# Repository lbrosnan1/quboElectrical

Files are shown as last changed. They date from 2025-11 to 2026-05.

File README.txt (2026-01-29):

Guys I have no idea what I'm doing here so if you have any suggestions lmk -Liam

Rules:

1) Only commit changes to the card you are meant to be working on
2) leave helpful commit messages
3) you don't need to follow the naming scheme because I'm pretty sure we can just see the date the latest change was
4) Put cool silkscreen on your boards

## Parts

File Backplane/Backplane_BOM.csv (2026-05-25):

Id | Designator | Footprint | Quantity | Designation | Supplier and ref
1 | J11,J33,J17,J5,J18,J13,J8,J15,J29,J31,J34,J14,J9,J35,J28,J7,J37,J10,J32,J30,J27,J36 | JST_PH_B2B-PH-K_1x02_P2.00mm_Vertical | 22 | Conn_01x02
2 | J24,J25,J26,J21,J23,J20,J22,J19 | PinHeader_1x02_P2.54mm_Vertical | 8 | Conn_01x02_Pin
3 | R2,R1 | R_0805_2012Metric | 2 | 120
4 | R4,R3 | R_0805_2012Metric | 2 | 4.7k
5 | J3,J2,J1,J4 | CONN_650470-5_TYC | 4 | ~
6 | U1 | SOIC-8_3.9x4.9mm_P1.27mm | 1 | ~
7 | J6 | SUPERSABRE_2CIRCUIT | 1 | 1720420202
8 | J12 | Molex_Mini-Fit_Jr_5566-24A_2x12_P4.20mm_Vertical | 1 | Conn_02x12_Odd_Even
9 | C2 | C_0805_2012Metric | 1 | 22uF
10 | C1,C3 | C_0805_2012Metric | 2 | 100nF

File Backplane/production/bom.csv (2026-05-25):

Designator | Footprint | Quantity | Value | LCSC Part #
C1, C3 | 0805 | 2 | 100nF
C2 | 0805 | 1 | 22uF
J1, J2, J3, J4 | CONN_650470-5_TYC | 4 | ~
J10, J11, J13, J14, J15, J17, J18, J27, J28, J29, J30, J31, J32, J33, J34, J35, J36, J37, J5, J7, J8, J9 | JST_PH_B2B-PH-K_1x02_P2.00mm_Vertical | 22 | Conn_01x02
J12 | Molex_Mini-Fit_Jr_5566-24A_2x12_P4.20mm_Vertical | 1 | Conn_02x12_Odd_Even
J19, J20, J21, J22, J23, J24, J25, J26 | PinHeader_1x02_P2.54mm_Vertical | 8 | Conn_01x02_Pin
J6 | SUPERSABRE_2CIRCUIT | 1 | 1720420202
R1, R2 | 0805 | 2 | 120
R3, R4 | 0805 | 2 | 4.7k
U1 | SOIC-8_3.9x4.9mm_P1.27mm | 1 | ~

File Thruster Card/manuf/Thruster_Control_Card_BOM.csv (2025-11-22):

Reference | Qty | Value | DNP | Exclude from BOM | Exclude from Board | Footprint | Datasheet
C1,C2 | 2 | 20pf |  |  |  | Capacitor_SMD:C_01005_0402Metric | ~
C4 | 1 | 4.7uF |  |  |  | Capacitor_SMD:C_0805_2012Metric_Pad1.18x1.45mm_HandSolder | ~
C5,C6,C7,T_C1,T_C3 | 5 | 100nF |  |  |  | Capacitor_SMD:C_0805_2012Metric_Pad1.18x1.45mm_HandSolder | ~
C8 | 1 | 1uF |  |  |  | Capacitor_SMD:C_0805_2012Metric_Pad1.18x1.45mm_HandSolder | ~
C9 | 1 | 22uF |  |  |  | Capacitor_SMD:C_0805_2012Metric_Pad1.18x1.45mm_HandSolder | ~
D1 | 1 | Green |  |  |  | LED_SMD:LED_1206_3216Metric_Pad1.42x1.75mm_HandSolder | ~
J1 | 1 | ~ |  |  |  | custom_components:6509475
J6 | 1 | Screw_Terminal_01x03 |  |  |  | custom_components:screw_junc_254_3by1 | ~
J7 | 1 | Screw_Terminal_01x02 |  |  |  | custom_components:screw_junc_254_2by1 | ~
R1 | 1 | 1k |  |  |  | Resistor_SMD:R_1206_3216Metric_Pad1.30x1.75mm_HandSolder | ~
R6 | 1 | 10k |  |  |  | Resistor_SMD:R_0805_2012Metric_Pad1.20x1.40mm_HandSolder | ~
SW1 | 1 | EG1218 |  |  |  | custom_components:slide_switch_EGER1218_Thruster | EG1218
U1,U3 | 2 | ~ |  |  |  | custom_components:ESC
U2,U4 | 2 | ~ |  |  |  | Thruster_Control_Card_Custom_Footprints:ESC
U5 | 1 | STM32G0B1RETx |  |  |  | Package_QFP:LQFP-64_10x10mm_P0.5mm | https://www.st.com/resource/en/datasheet/stm32g0b1re.pdf
U6 | 1 | ATA6561-GAQW-N |  |  |  | custom_components:SOIC8_4P9X3P9MC_MCH | ATA6561-GAQW-N
U7 | 1 | ~ |  |  |  | custom_components:YSX321SC_HSE_Oscillator

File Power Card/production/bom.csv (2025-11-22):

Designator | Footprint | Quantity | Value | LCSC Part #
C3, C6 | 0805 | 2 | 1u
J2 | 6509475 | 1 | ~
J3 | SolderWire-1.5sqmm_1x03_P7.8mm_D1.7mm_OD3.9mm | 1 | Conn_01x03_Pin
J4 | 1.25__FUSECLIPS | 1 | Conn_01x04_Pin
Q1 | TO-220-3_Vertical | 1 | FQPF27P06
R1, R2 | 0805 | 2 | 10kO
U1 | 240W_CONV | 1 | ~
U2 | CONV_UWE-24_3-Q12P-C | 1 | ~
U3 | TSR2 | 1 | TSR2-2450
U4 | TSR2 | 1 | TSR2-2433

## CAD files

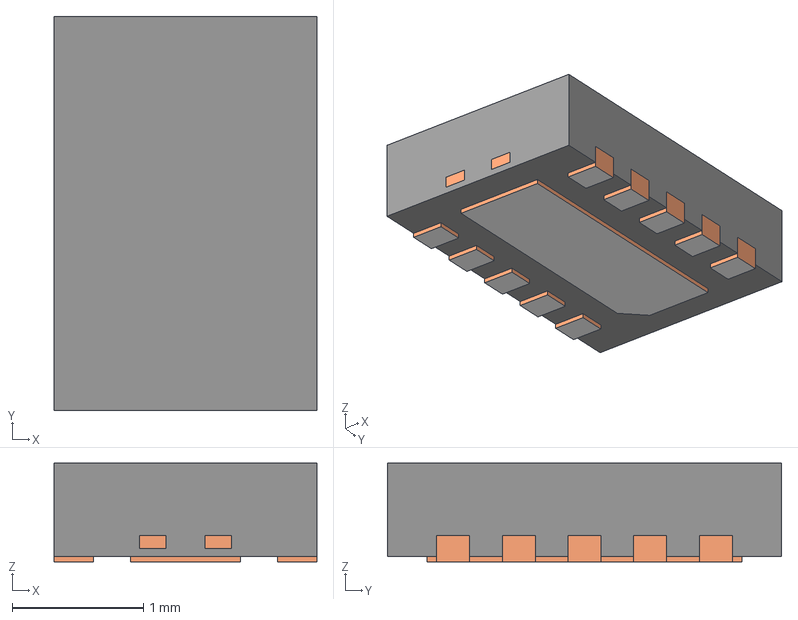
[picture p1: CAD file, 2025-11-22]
BMS Card/DQC0010A.stp
2.00 x 3.00 x 0.75 mm
MOLD-DQC0010A
FRAME-DQC0010A

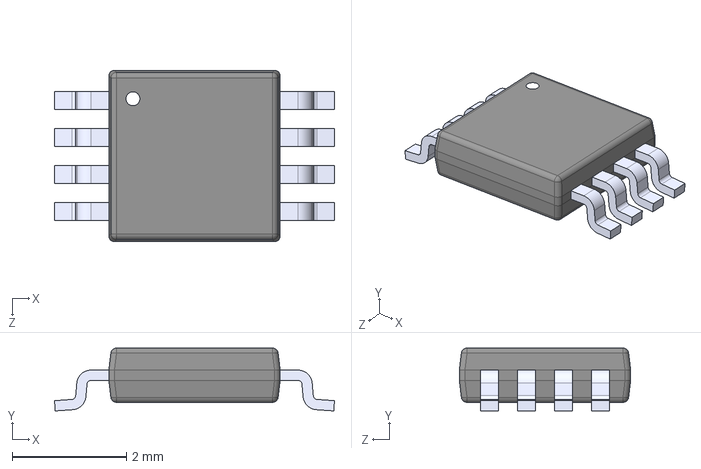
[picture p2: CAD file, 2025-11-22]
Pneumatics Card/3D models/TCA4307DGKR.STEP
4.90 x 1.10 x 3.00 mm

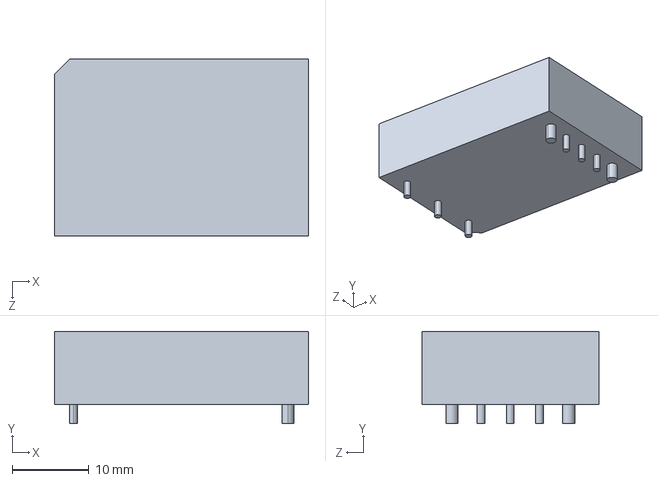
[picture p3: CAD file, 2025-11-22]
Power Card/3D_models/SRS3120N006N25W.STEP
33.1 x 12.0 x 23.1 mm

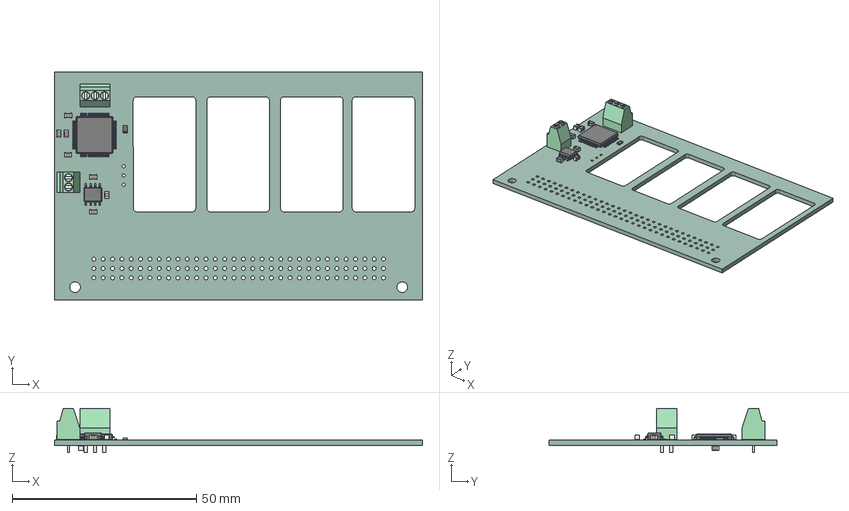
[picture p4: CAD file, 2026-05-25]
Thruster Card/Thruster_Control_Card.step
100.0 x 61.9 x 12.0 mm
TerminalBlock_Phoenix_MPT-0,5-2-2.54_1x02_P2.54mm_Horizontal
SO-8_3.9x4.9mm_P1.27mm
C_0805_2012Metric x 8
TerminalBlock_Phoenix_MPT-0,5-3-2.54_1x03_P2.54mm_Horizontal
R_0805_2012Metric
LQFP-64_10x10mm_P0.5mm
Thruster_Control_Card_PCB

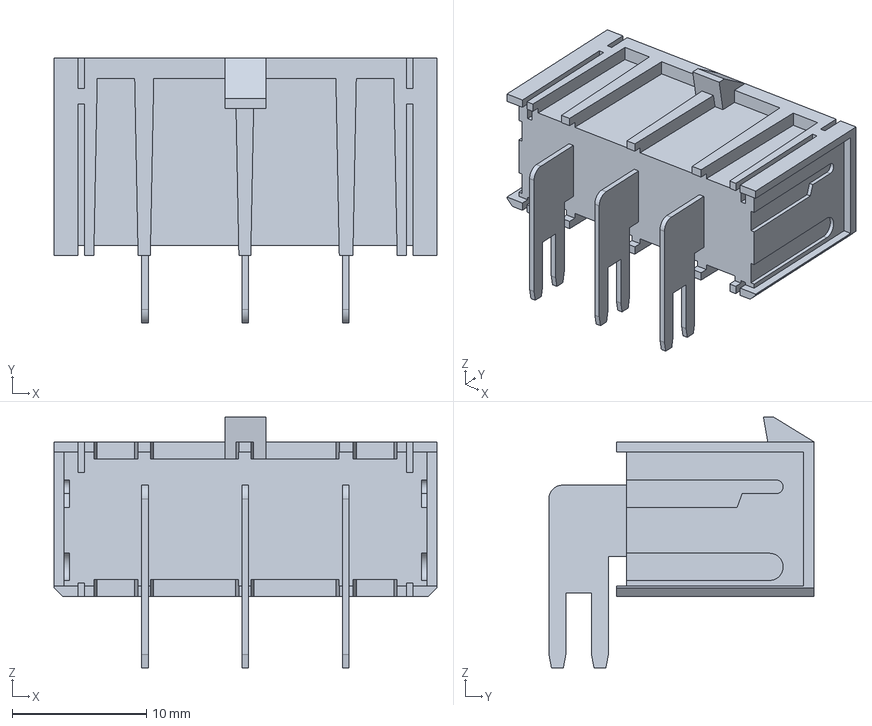
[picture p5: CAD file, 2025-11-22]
Power Card/3D_models/Saber_connector.stp
28.6 x 19.8 x 18.7 mm

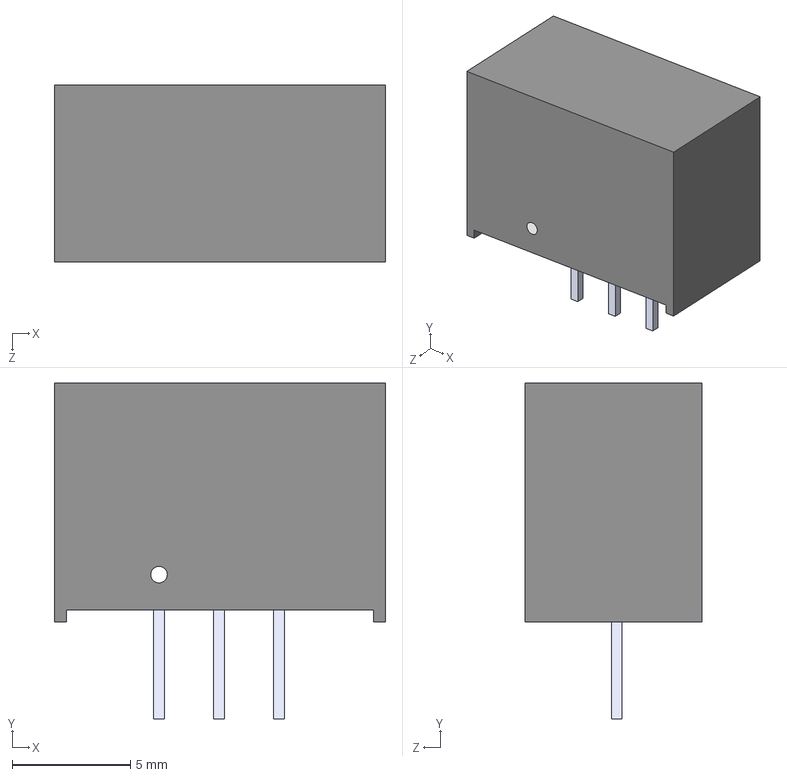
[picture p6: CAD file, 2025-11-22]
Power Card/3D_models/TSR_2-2450.step
14.0 x 14.2 x 7.50 mm

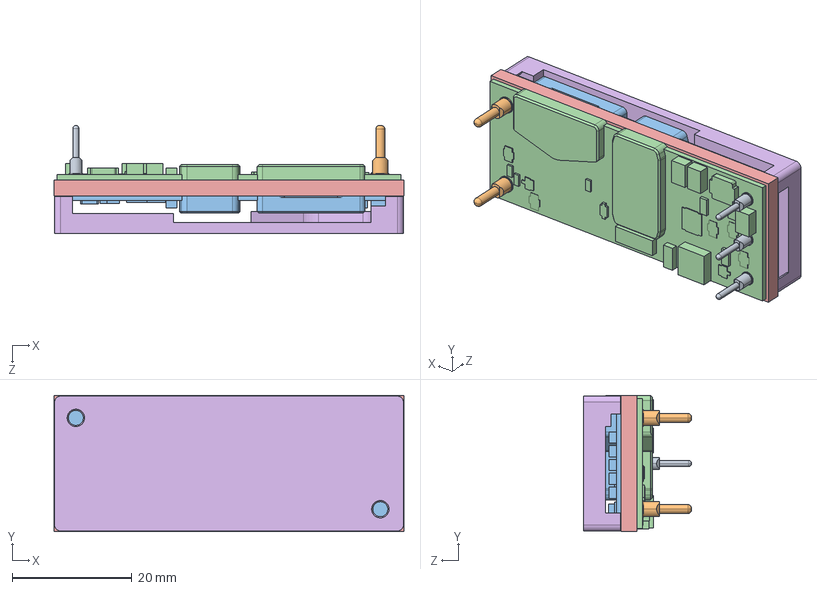
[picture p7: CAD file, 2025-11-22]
Power Card/3D_models/pkb2213dpihs.STEP
58.4 x 22.7 x 18.1 mm
pkb2213dpihs_01
pkb2213dpihs_02
pkb2213dpihs_03
pkb2213dpihs_04
pkb2213dpihs_05
pkb2213dpihs_06
pkb2213dpihs_07
pkb2213dpihs_08
pkb2213dpihs_09

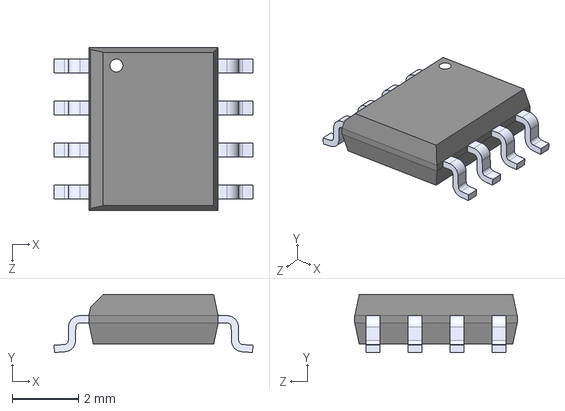
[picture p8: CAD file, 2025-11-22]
Power Card/3D_models/TMCS1101A4BQDR.step
6.00 x 1.75 x 4.90 mm

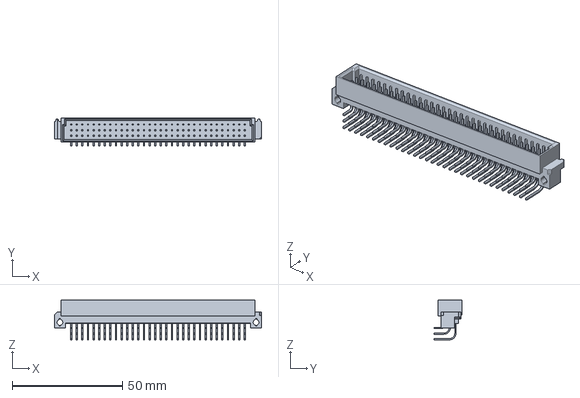
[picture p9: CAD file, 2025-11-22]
Power Card/3D_models/650947-5.stp
93.8 x 12.8 x 18.0 mm

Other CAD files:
Power Card/3D_models/SRS3120N006N25W.SLDPRT.STEP
Power Card/3D_models/SRS3120N006N25W.SLDPRT

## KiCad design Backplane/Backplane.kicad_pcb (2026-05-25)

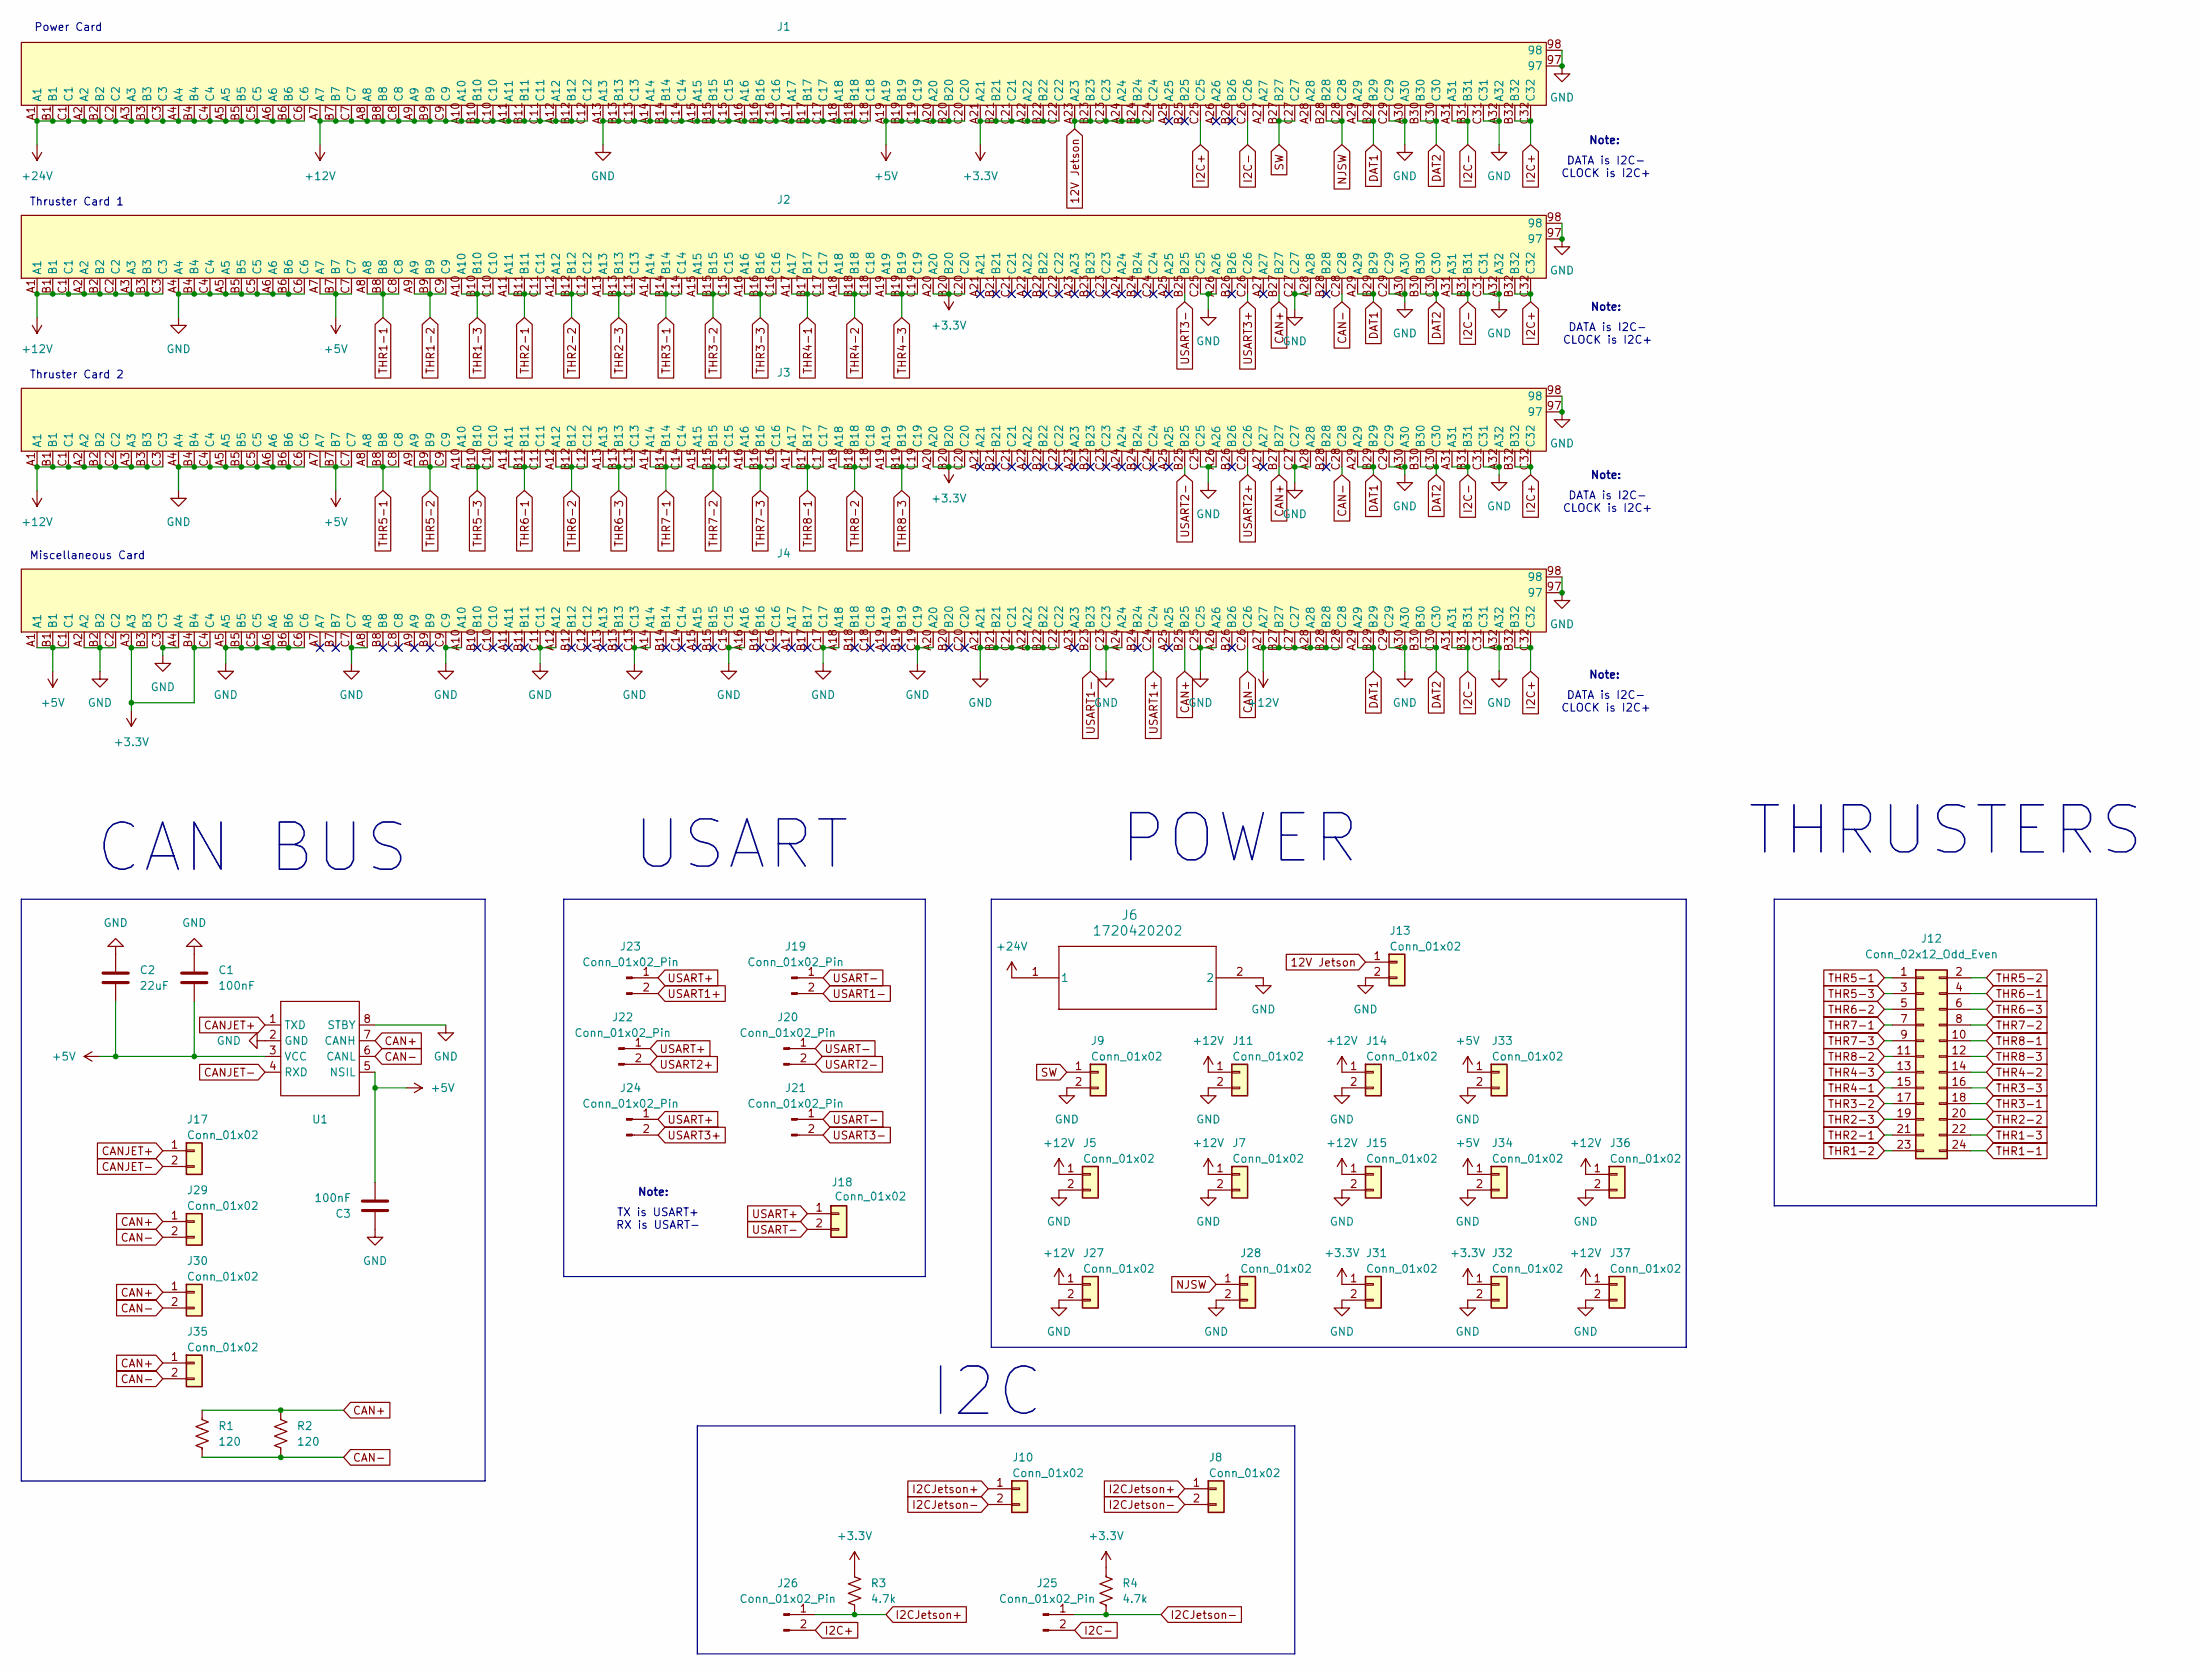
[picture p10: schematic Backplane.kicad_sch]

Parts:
C1, C3: 100nF; C_0805_2012Metric
C2: 22uF; C_0805_2012Metric
J1, J2, J3, J4: CONN_650470-5_TYC
J5, J7, J8, J9, J10, J11, J13, J14, J15, J17, J18, J27, J28, J29, J30, J31, J32, J33, J34, J35, J36, J37: Conn_01x02; JST_PH_B2B-PH-K_1x02_P2.00mm_Vertical
J6: 1720420202; SUPERSABRE_2CIRCUIT
J12: Conn_02x12_Odd_Even; Molex_Mini-Fit_Jr_5566-24A_2x12_P4.20mm_Vertical
J19, J20, J21, J22, J23, J24, J25, J26: Conn_01x02_Pin; PinHeader_1x02_P2.54mm_Vertical
R1, R2: 120; R_0805_2012Metric
R3, R4: 4.7k; R_0805_2012Metric
U1: SOIC-8_3.9x4.9mm_P1.27mm

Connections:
12V Jetson: J1.A23, J1.A24, J1.B23, J1.B24, J1.C23, J1.C24, J13.1
+3.3V: J1.A21, J1.A22, J1.B21, J1.B22, J1.C21, J1.C22, J2.A20, J2.B20, J2.C20, J3.A20, J3.B20, J3.C20, J4.A3, J4.B3, J4.B4, J4.C4, J31.1, J32.1, R3.1, R4.1
+5V: C1.2, C2.2, C3.2, J1.A19, J1.A20, J1.B19, J1.B20, J1.C19, J1.C20, J2.A7, J2.B7, J2.C7, J3.A7, J3.B7, J3.C7, J4.A1, J4.B1, J4.C1, J33.1, J34.1, U1.3 (VCC), U1.5 (NSIL)
+12V: J1.A7, J1.A8, J1.A9, J1.A10, J1.A11, J1.A12, J1.B7, J1.B8, J1.B9, J1.B10, J1.B11, J1.B12, J1.C7, J1.C8, J1.C9, J1.C10, J1.C11, J1.C12, J2.A1, J2.A2, J2.A3, J2.B1, J2.B2, J2.B3, J2.C1, J2.C2, J2.C3, J3.A1, J3.A2, J3.A3, J3.B1, J3.B2, J3.B3, J3.C1, J3.C2, J3.C3, J4.A27, J4.A28, J4.B27, J4.B28, J4.C27, J4.C28, J5.1, J7.1, J11.1, J14.1, J15.1, J27.1, J36.1, J37.1
+24V: J1.A1, J1.A2, J1.A3, J1.A4, J1.A5, J1.A6, J1.B1, J1.B2, J1.B3, J1.B4, J1.B5, J1.B6, J1.C1, J1.C2, J1.C3, J1.C4, J1.C5, J1.C6, J6.1
CAN+: J2.B27, J3.B27, J4.B25, J29.1, J30.1, J35.1, R1.1, R2.1, U1.7 (CANH)
CAN-: J2.C28, J3.C28, J4.C26, J29.2, J30.2, J35.2, R1.2, R2.2, U1.6 (CANL)
CANJET+: J17.1, U1.1 (TXD)
CANJET-: J17.2, U1.4 (RXD)
DAT1: J1.A29, J1.B29, J2.A29, J2.B29, J3.A29, J3.B29, J4.A29, J4.B29
DAT2: J1.B30, J1.C30, J2.B30, J2.C30, J3.B30, J3.C30, J4.B30, J4.C30
GND: C1.1, C2.1, C3.1, J1.97, J1.98, J1.A13, J1.A14, J1.A15, J1.A16, J1.A17, J1.A18, J1.A30, J1.A32, J1.B13, J1.B14, J1.B15, J1.B16, J1.B17, J1.B18, J1.C13, J1.C14, J1.C15, J1.C16, J1.C17, J1.C18, J1.C29, J1.C31, J2.97, J2.98, J2.A4, J2.A5, J2.A6, J2.A26, J2.A28, J2.A30, J2.A32, J2.B4, J2.B5, J2.B6, J2.C4, J2.C5, J2.C6, J2.C25, J2.C27, J2.C29, J2.C31, J3.97, J3.98, J3.A4, J3.A5, J3.A6, J3.A26, J3.A28, J3.A30, J3.A32, J3.B4, J3.B5, J3.B6, J3.C4, J3.C5, J3.C6, J3.C25, J3.C27, J3.C29, J3.C31, J4.97, J4.98, J4.A2, J4.A4, J4.A5, J4.A6, J4.A8, J4.A10, J4.A12, J4.A14, J4.A16, J4.A18, J4.A20, J4.A21, J4.A22, J4.A24, J4.A26, J4.A30, J4.A32, J4.B2, J4.B5, J4.B6, J4.B21, J4.B22, J4.C2, J4.C3, J4.C5, J4.C6, J4.C7, J4.C9, J4.C11, J4.C13, J4.C15, J4.C17, J4.C19, J4.C21, J4.C22, J4.C23, J4.C25, J4.C29, J4.C31, J5.2, J6.2, J7.2, J9.2, J11.2, J13.2, J14.2, J15.2, J27.2, J28.2, J31.2, J32.2, J33.2, J34.2, J36.2, J37.2, U1.2 (GND), U1.8 (STBY)
I2C+: J1.B32, J1.C25, J1.C32, J2.B32, J2.C32, J3.B32, J3.C32, J4.B32, J4.C32, J26.2
I2C-: J1.A31, J1.B31, J1.C26, J2.A31, J2.B31, J3.A31, J3.B31, J4.A31, J4.B31, J25.2
I2CJetson+: J8.1, J10.1, J26.1, R3.2
I2CJetson-: J8.2, J10.2, J25.1, R4.2
NJSW: J1.B28, J1.C28, J28.1
SW: J1.B27, J1.C27, J9.1
THR1-1: J2.A8, J2.B8, J2.C8, J12.24
THR1-2: J2.A9, J2.B9, J2.C9, J12.23
THR1-3: J2.A10, J2.B10, J2.C10, J12.22
THR2-1: J2.A11, J2.B11, J2.C11, J12.21
THR2-2: J2.A12, J2.B12, J2.C12, J12.20
THR2-3: J2.A13, J2.B13, J2.C13, J12.19
THR3-1: J2.A14, J2.B14, J2.C14, J12.18
THR3-2: J2.A15, J2.B15, J2.C15, J12.17
THR3-3: J2.A16, J2.B16, J2.C16, J12.16
THR4-1: J2.A17, J2.B17, J2.C17, J12.15
THR4-2: J2.A18, J2.B18, J2.C18, J12.14
THR4-3: J2.A19, J2.B19, J2.C19, J12.13
THR5-1: J3.A8, J3.B8, J3.C8, J12.1
THR5-2: J3.A9, J3.B9, J3.C9, J12.2
THR5-3: J3.A10, J3.B10, J3.C10, J12.3
THR6-1: J3.A11, J3.B11, J3.C11, J12.4
THR6-2: J3.A12, J3.B12, J3.C12, J12.5
THR6-3: J3.A13, J3.B13, J3.C13, J12.6
THR7-1: J3.A14, J3.B14, J3.C14, J12.7
THR7-2: J3.A15, J3.B15, J3.C15, J12.8
THR7-3: J3.A16, J3.B16, J3.C16, J12.9
THR8-1: J3.A17, J3.B17, J3.C17, J12.10
THR8-2: J3.A18, J3.B18, J3.C18, J12.11
THR8-3: J3.A19, J3.B19, J3.C19, J12.12
USART1+: J4.C24, J23.2
USART1-: J4.B23, J19.2
USART2+: J3.C26, J22.2
USART2-: J3.B25, J20.2
USART3+: J2.C26, J24.2
USART3-: J2.B25, J21.2
USART+: J18.1, J22.1, J23.1, J24.1
USART-: J18.2, J19.1, J20.1, J21.1

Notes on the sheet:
I2C
Note:
POWER
Thruster Card 1
DATA is I2C- CLOCK is I2C+
Miscellaneous Card
THRUSTERS
Power Card
USART
Thruster Card 2
CAN BUS
TX is USART+ RX is USART-

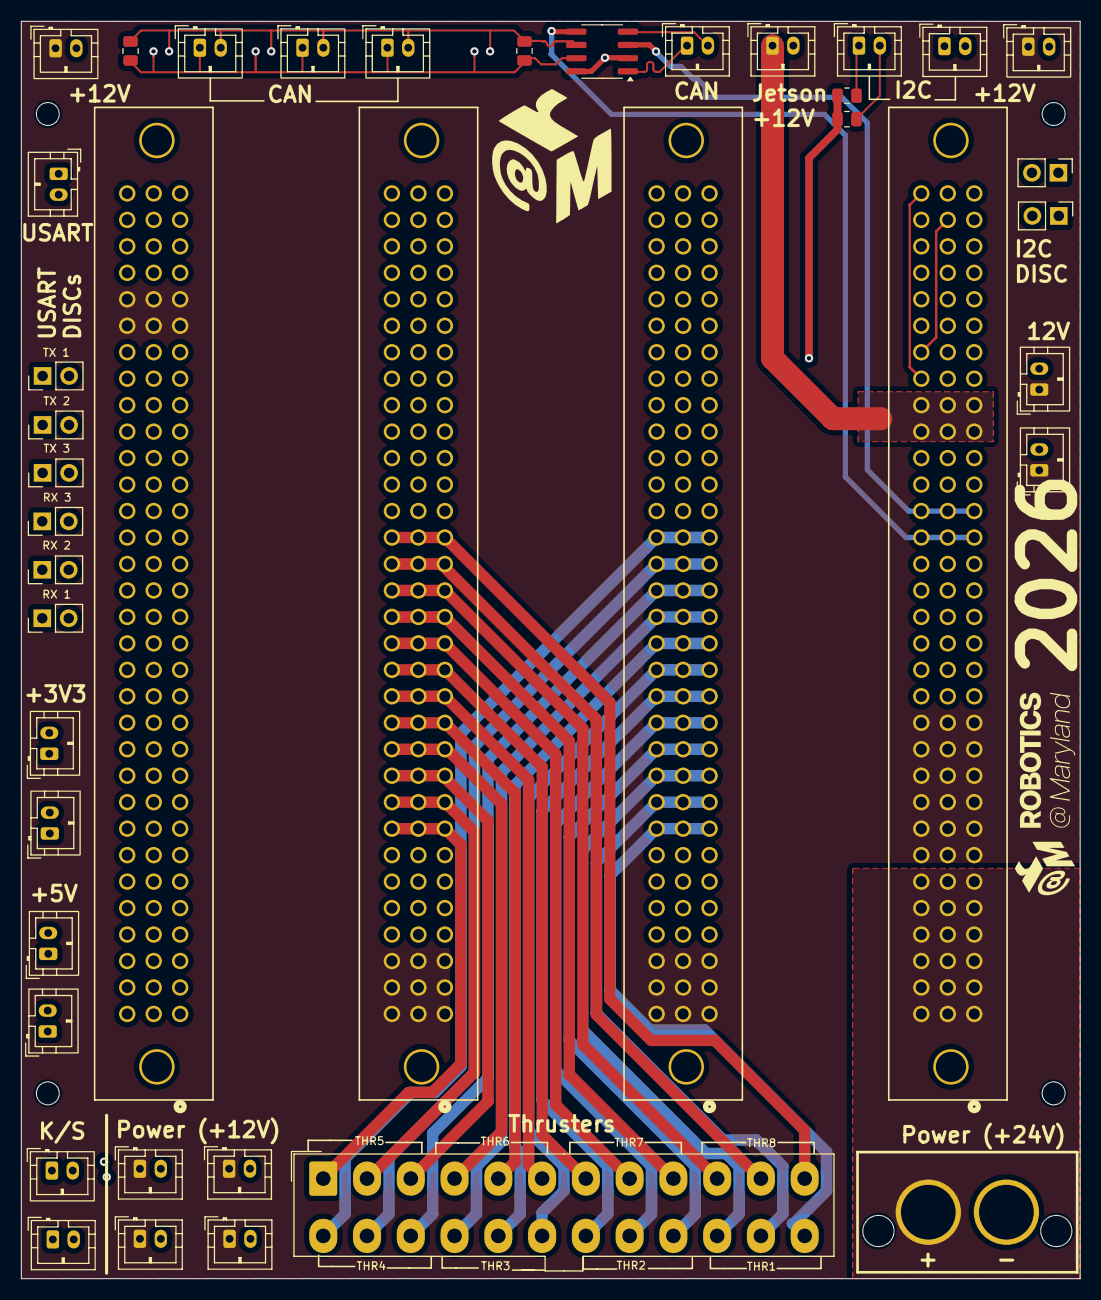
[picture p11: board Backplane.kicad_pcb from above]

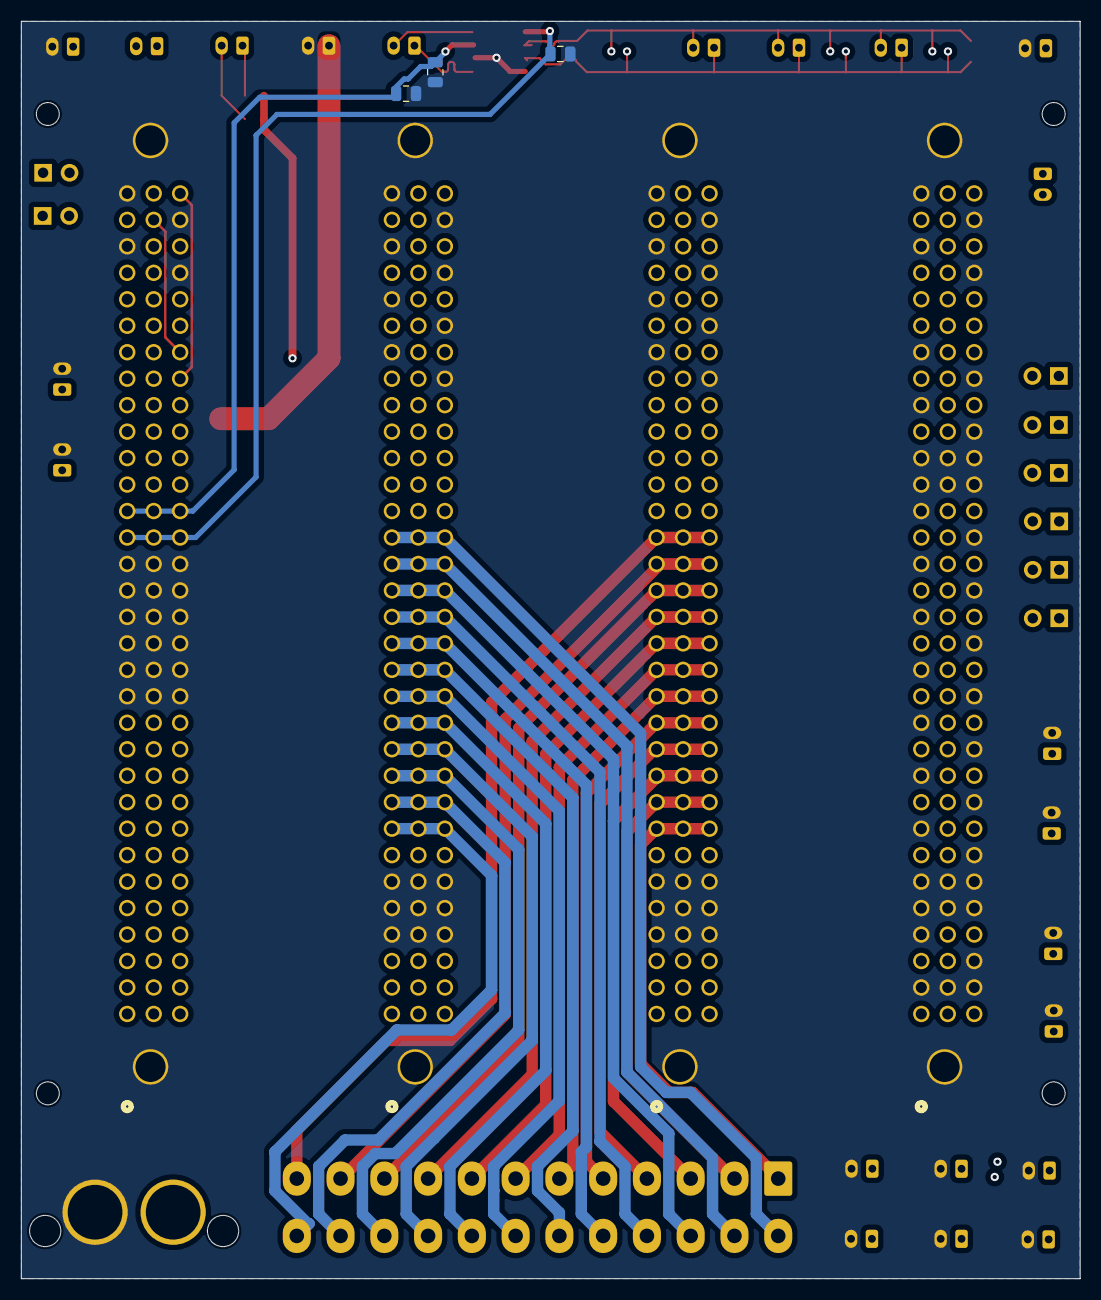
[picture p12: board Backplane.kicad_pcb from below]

Board: 4 copper layers, 101.6 x 120.6 mm, 44 parts (3 on the bottom side), 50 nets.

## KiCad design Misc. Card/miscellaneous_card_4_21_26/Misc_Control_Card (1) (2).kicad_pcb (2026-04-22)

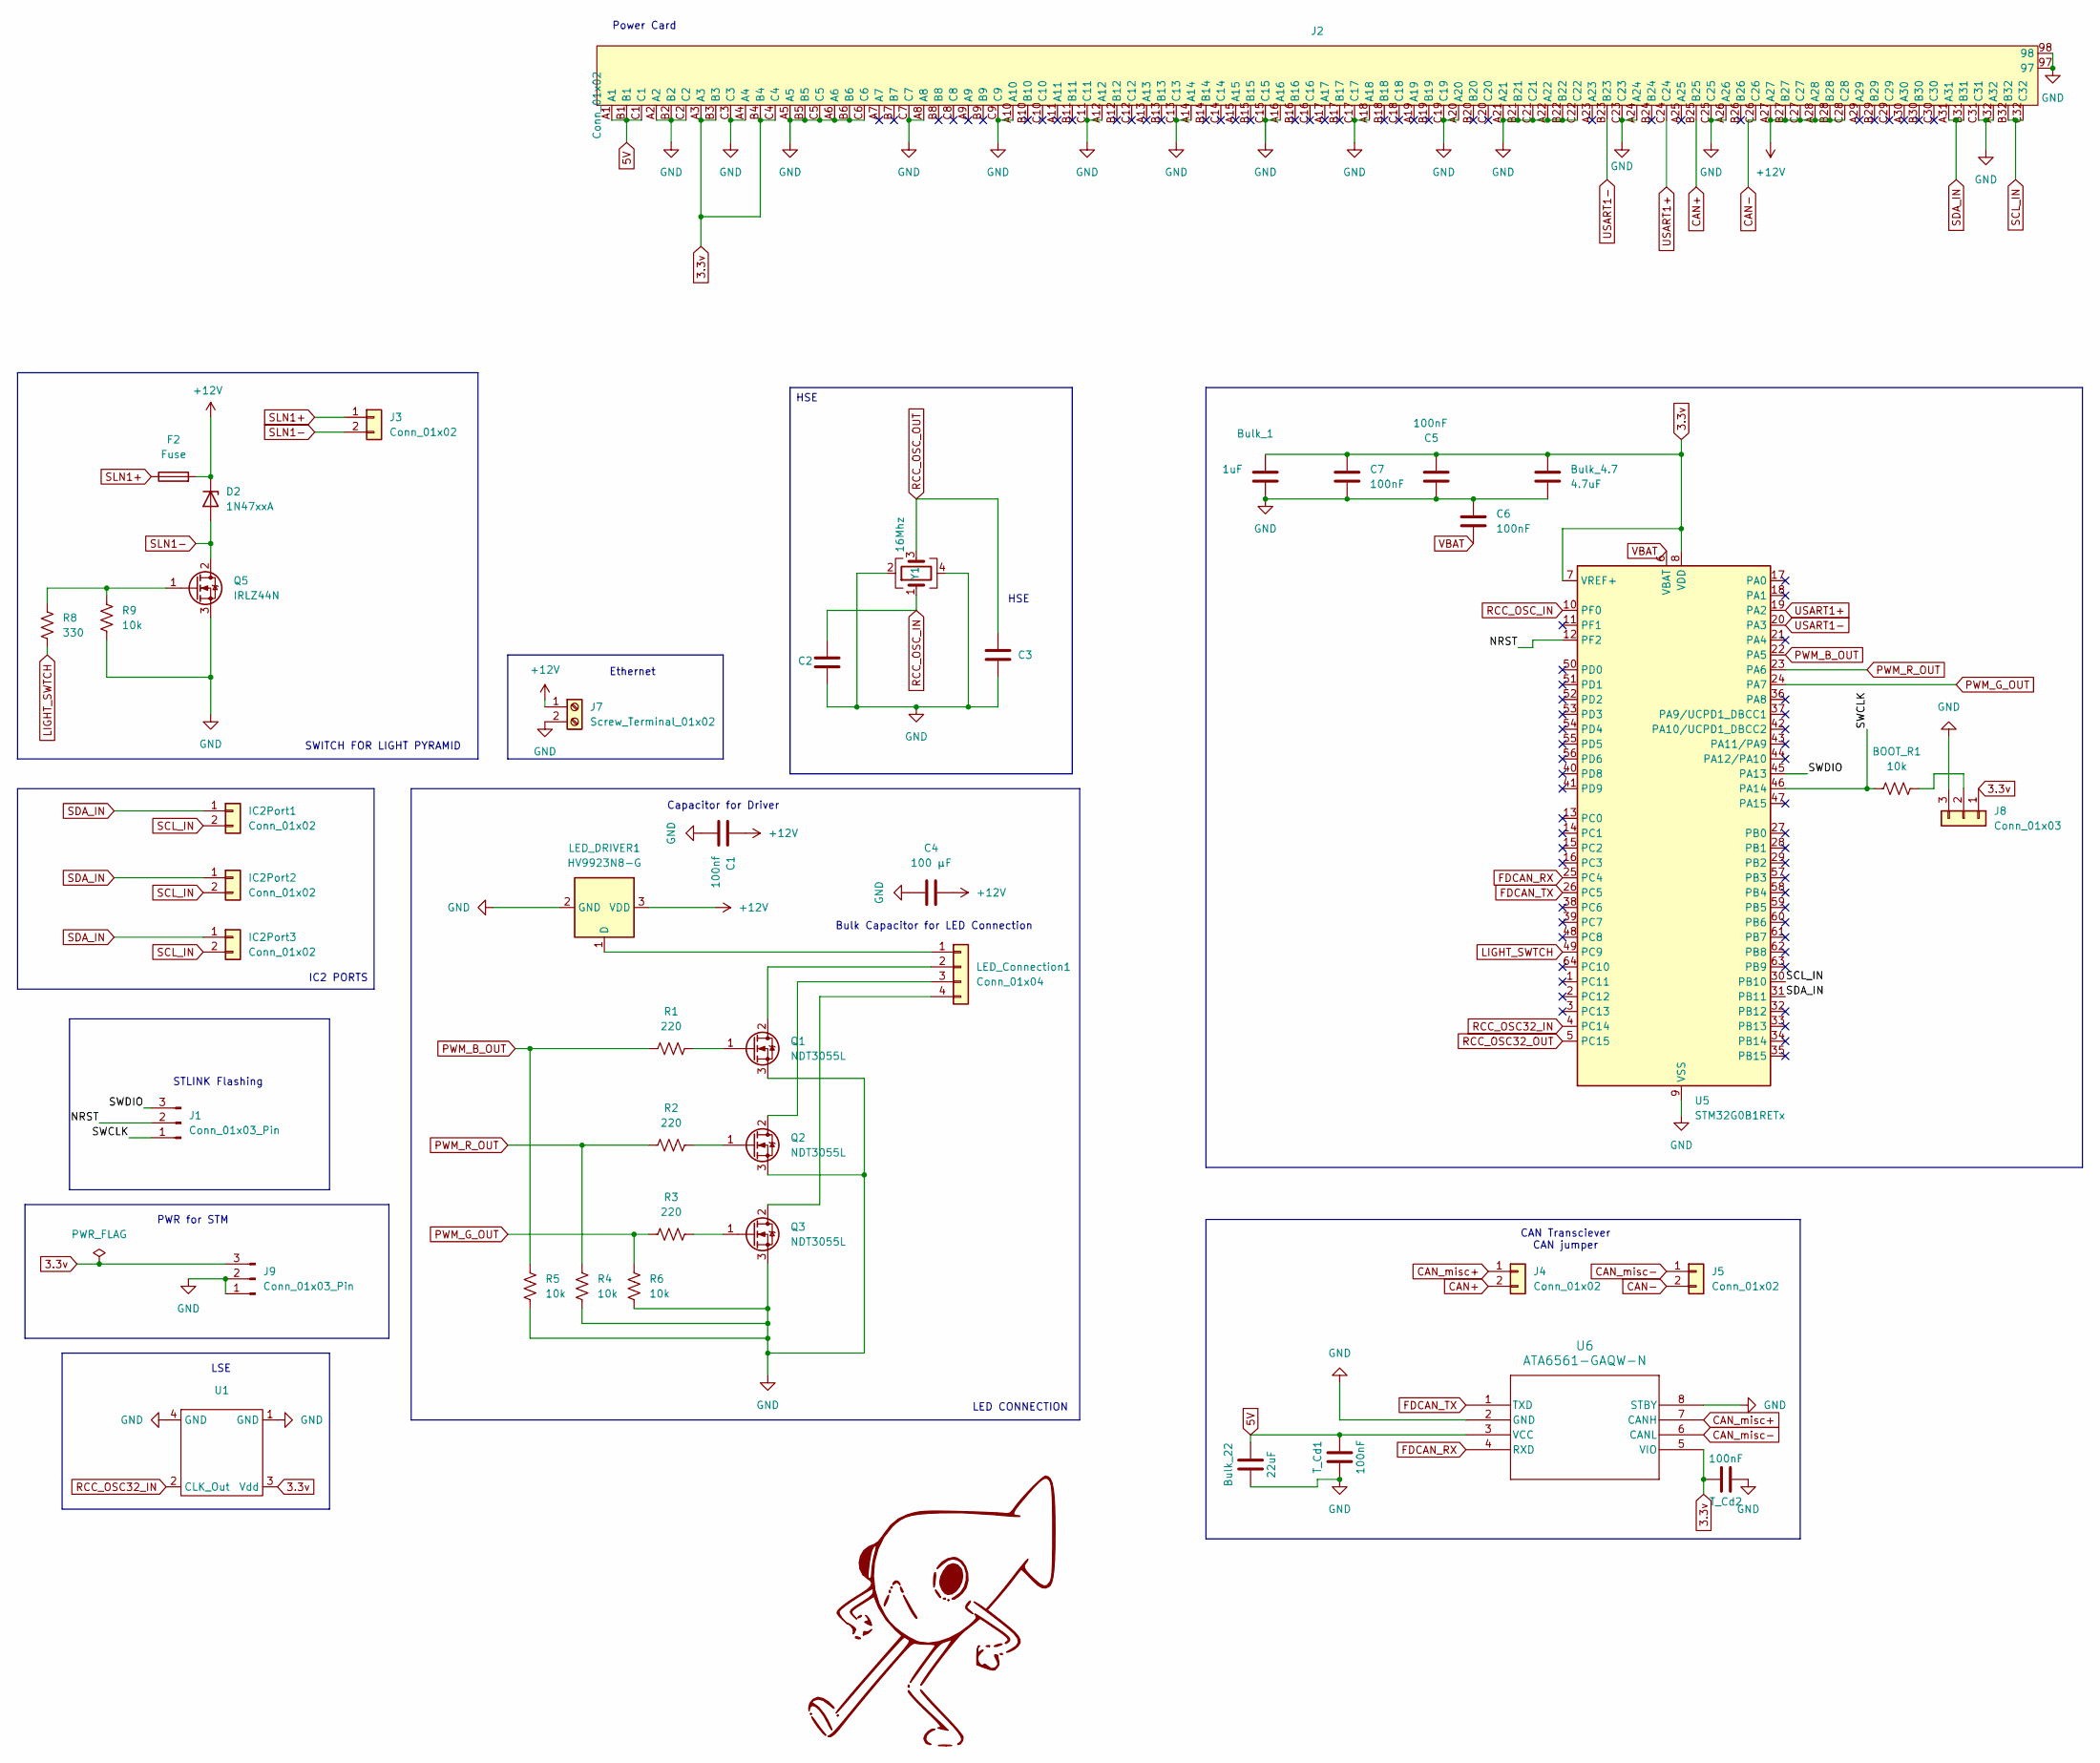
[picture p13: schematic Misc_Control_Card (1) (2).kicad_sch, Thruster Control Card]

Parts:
BOOT_R1: 10k; R_0805_2012Metric_Pad1.20x1.40mm_HandSolder
Bulk_1: 1uF; C_0805_2012Metric_Pad1.18x1.45mm_HandSolder
Bulk_4.7: 4.7uF; C_0805_2012Metric_Pad1.18x1.45mm_HandSolder
Bulk_22: 22uF; C_0805_2012Metric_Pad1.18x1.45mm_HandSolder
C1: 100nf; C_0805_2012Metric_Pad1.18x1.45mm_HandSolder
C2, C3: 10pF; C_0805_2012Metric_Pad1.18x1.45mm_HandSolder
C4: 100 µF; C_0805_2012Metric_Pad1.18x1.45mm_HandSolder
C5, C6, C7: 100nF; C_0805_2012Metric_Pad1.18x1.45mm_HandSolder
D2: 1N47xxA; D_DO-41_SOD81_P10.16mm_Horizontal
F2: Fuse; Fuseholder_Littelfuse_Nano2_154x
IC2Port1, IC2Port2, IC2Port3: Conn_01x02; JST_PH_B2B-PH-K_1x02_P2.00mm_Vertical
J1, J9: Conn_01x03_Pin; PinHeader_1x03_P2.54mm_Vertical
J2: Conn_01x02; 6509475
J3: Conn_01x02; JST_PH_B2B-PH-K_1x02_P2.00mm_Vertical
J4, J5: Conn_01x02; PinHeader_1x02_P2.54mm_Vertical
J7: Screw_Terminal_01x02; screw_junc_254_2by1
J8: Conn_01x03; slide_switch_EGER1218_Thruster
LED_Connection1: Conn_01x04; JST_EH_B4B-EH-A_1x04_P2.50mm_Vertical
LED_DRIVER1: HV9923N8-G; SOT-89-3
Q1, Q2, Q3: NDT3055L; SOT-223-3_TabPin2
Q5: IRLZ44N; TO-220-3_Vertical
R1, R2, R3: 220; R_0805_2012Metric_Pad1.20x1.40mm_HandSolder
R4, R5, R6, R9: 10k; R_0805_2012Metric_Pad1.20x1.40mm_HandSolder
R8: 330; R_0805_2012Metric_Pad1.20x1.40mm_HandSolder
T_Cd1, T_Cd2: 100nF; C_0805_2012Metric_Pad1.18x1.45mm_HandSolder
U1: SiT1552
U5: STM32G0B1RETx; LQFP-64_10x10mm_P0.5mm
U6: ATA6561-GAQW-N; SOIC8_4P9X3P9MC_MCH
Y1: 16Mhz; Crystal_SMD_3225-4Pin_3.2x2.5mm_HandSoldering

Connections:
3.3v: Bulk_1.2, Bulk_4.7.1, C5.1, C7.1, J1.A3, J1.B3, J1.B4, J1.C4, J2.A3, J2.B3, J2.B4, J2.C4, J8.1, J9.3, T_Cd2.1, U1.3 (Vdd), U5.7 (VREF+), U5.8 (VDD), U6.5 (VIO); also elsewhere on the board
5V: Bulk_22.1, J2.A1, J2.B1, J2.C1, T_Cd1.1, U6.3 (VCC)
+12V: C1.1, C4.1, D2.1 (K), F2.2, J1.A27, J1.A28, J1.B27, J1.B28, J1.C27, J1.C28, J2.A27, J2.A28, J2.B27, J2.B28, J2.C27, J2.C28, J7.1, LED_DRIVER1.3 (VDD); also elsewhere on the board
/NRST: J1.2, U5.12 (PF2)
/SWCLK: BOOT_R1.1, J1.1, U5.46 (PA14)
/SWDIO: J1.3, U5.45 (PA13)
CAN+: J2.B25, J4.2
CAN-: J2.C26, J5.2
CAN_misc+: J4.1, U6.7 (CANH)
CAN_misc-: J5.1, U6.6 (CANL)
FDCAN_RX: U5.25 (PC4), U6.4 (RXD)
FDCAN_TX: U5.26 (PC5), U6.1 (TXD)
GND: Bulk_1.1, Bulk_4.7.2, Bulk_22.2, C1.2, C2.2, C3.2, C4.2, C5.2, C6.1, C7.2, J1.97, J1.98, J1.A2, J1.A4, J1.A5, J1.A6, J1.A8, J1.A10, J1.A12, J1.A14, J1.A16, J1.A18, J1.A20, J1.A21, J1.A22, J1.A24, J1.A26, J1.A32, J1.B2, J1.B5, J1.B6, J1.B21, J1.B22, J1.C2, J1.C3, J1.C5, J1.C6, J1.C7, J1.C9, J1.C11, J1.C13, J1.C15, J1.C17, J1.C19, J1.C21, J1.C22, J1.C23, J1.C25, J1.C31, J2.97, J2.98, J2.A2, J2.A4, J2.A5, J2.A6, J2.A8, J2.A10, J2.A12, J2.A14, J2.A16, J2.A18, J2.A20, J2.A21, J2.A22, J2.A24, J2.A26, J2.A32, J2.B2, J2.B5, J2.B6, J2.B21, J2.B22, J2.C2, J2.C3, J2.C5, J2.C6, J2.C7, J2.C9, J2.C11, J2.C13, J2.C15, J2.C17, J2.C19, J2.C21, J2.C22, J2.C23, J2.C25, J2.C31, J7.2, J8.3, J9.1, J9.2, LED_DRIVER1.2 (GND), Q1.3 (S), Q2.3 (S), Q3.3 (S), Q5.3 (S), R4.1, R5.1, R6.1, R9.2, T_Cd1.2, T_Cd2.2, U1.1 (GND), U1.4 (GND), U5.9 (VSS), U6.2 (GND), U6.8 (STBY), Y1.2, Y1.4; also elsewhere on the board
LIGHT_SWTCH: R8.1, U5.49 (PC9)
unnamed: BOOT_R1.2, J8.2
unnamed 15: LED_Connection1.1, LED_DRIVER1.1 (D); also elsewhere on the board
unnamed 16: LED_Connection1.2, Q1.2 (D); also elsewhere on the board
unnamed 17: LED_Connection1.3, Q2.2 (D); also elsewhere on the board
unnamed 18: LED_Connection1.4, Q3.2 (D); also elsewhere on the board
unnamed: Q1.1 (G), R1.2
unnamed: Q2.1 (G), R2.2
unnamed: Q3.1 (G), R3.2
unnamed 22: Q5.1 (G), R8.2, R9.1; also elsewhere on the board
PWM_B_OUT: R1.1, R5.2, U5.22 (PA5)
PWM_G_OUT: R3.1, R6.2, U5.24 (PA7)
PWM_R_OUT: R2.1, R4.2, U5.23 (PA6)
RCC_OSC32_IN: U1.2 (CLK_Out), U5.4 (PC14)
RCC_OSC32_OUT: U5.5 (PC15)
RCC_OSC_IN: C2.1, U5.10 (PF0), Y1.1
RCC_OSC_OUT: C3.1, Y1.3
SCL_IN: IC2Port1.2, IC2Port2.2, IC2Port3.2, J2.B32, J2.C32, U5.30 (PB10)
SDA_IN: IC2Port1.1, IC2Port2.1, IC2Port3.1, J2.A31, J2.B31, U5.31 (PB11)
SLN1+: F2.1, J3.1
SLN1-: D2.2 (A), J3.2, Q5.2 (D); also elsewhere on the board
USART1+: J2.C24, U5.19 (PA2)
USART1-: J2.B23, U5.20 (PA3)
VBAT: C6.2, U5.6 (VBAT)

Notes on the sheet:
Bulk Capacitor for LED Connection
Power Card
LSE
IC2 PORTS
Capacitor for Driver
STLINK Flashing
PWR for STM
CAN Transciever CAN jumper
SWITCH FOR LIGHT PYRAMID
HSE
LED CONNECTION
Ethernet
HSE

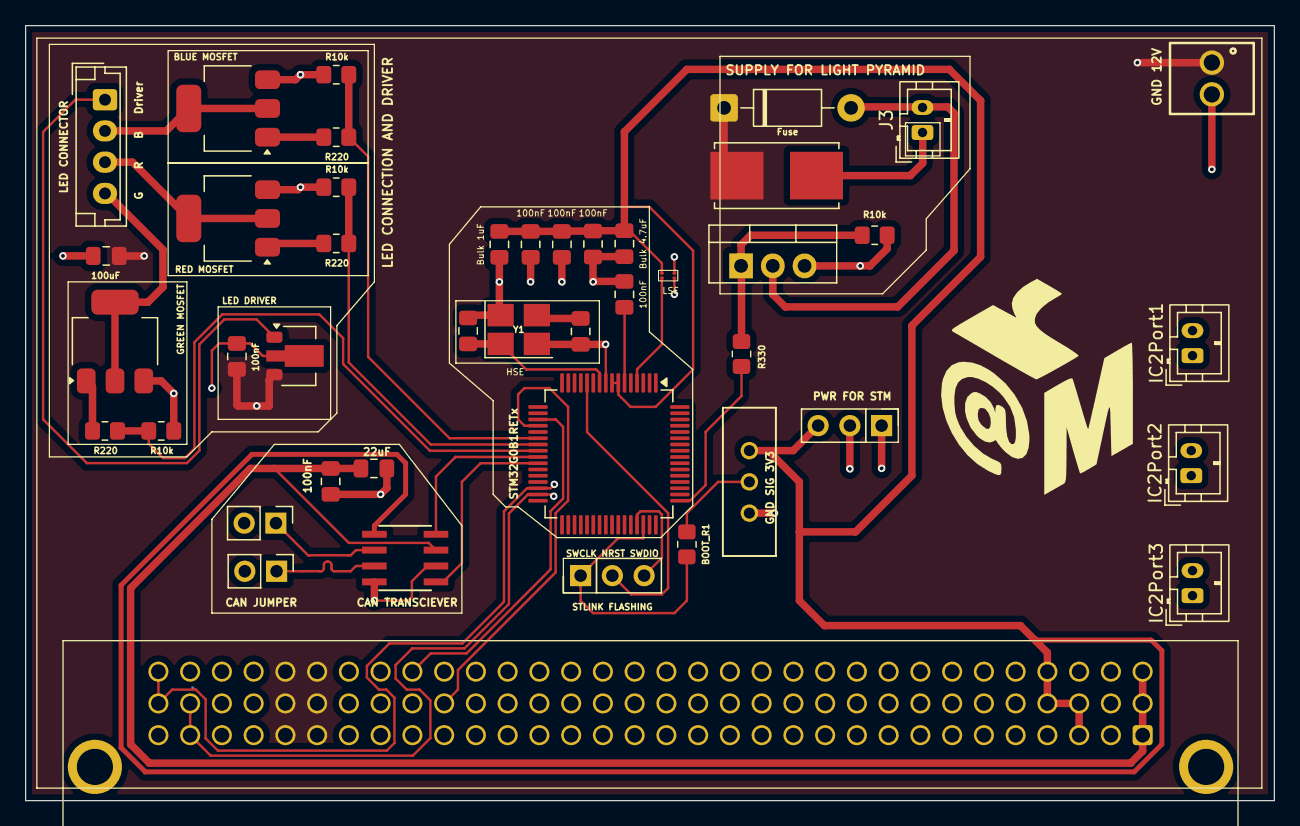
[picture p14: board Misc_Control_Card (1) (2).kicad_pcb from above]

Board: 4 copper layers, 99.9 x 62.0 mm, 44 parts (0 on the bottom side), 36 nets.

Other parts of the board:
Bulk 4.7uF: 4.7uF; C_0805_2012Metric_Pad1.18x1.45mm_HandSolder
Fuse: 1N47xxA; D_DO-41_SOD81_P10.16mm_Horizontal
LED Connection: Conn_01x04; JST_EH_B4B-EH-A_1x04_P2.50mm_Vertical
R10k: 10k; R_0805_2012Metric_Pad1.20x1.40mm_HandSolder

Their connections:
3.3v: Bulk 4.7uF.1; also elsewhere on the board
+12V: Fuse.1 (K); also elsewhere on the board
GND: Bulk 4.7uF.2, R10k.2; also elsewhere on the board
unnamed 15: LED Connection.1; also elsewhere on the board
unnamed 16: LED Connection.2; also elsewhere on the board
unnamed 17: LED Connection.3; also elsewhere on the board
unnamed 18: LED Connection.4; also elsewhere on the board
unnamed 22: R10k.1; also elsewhere on the board
SLN1-: Fuse.2 (A); also elsewhere on the board

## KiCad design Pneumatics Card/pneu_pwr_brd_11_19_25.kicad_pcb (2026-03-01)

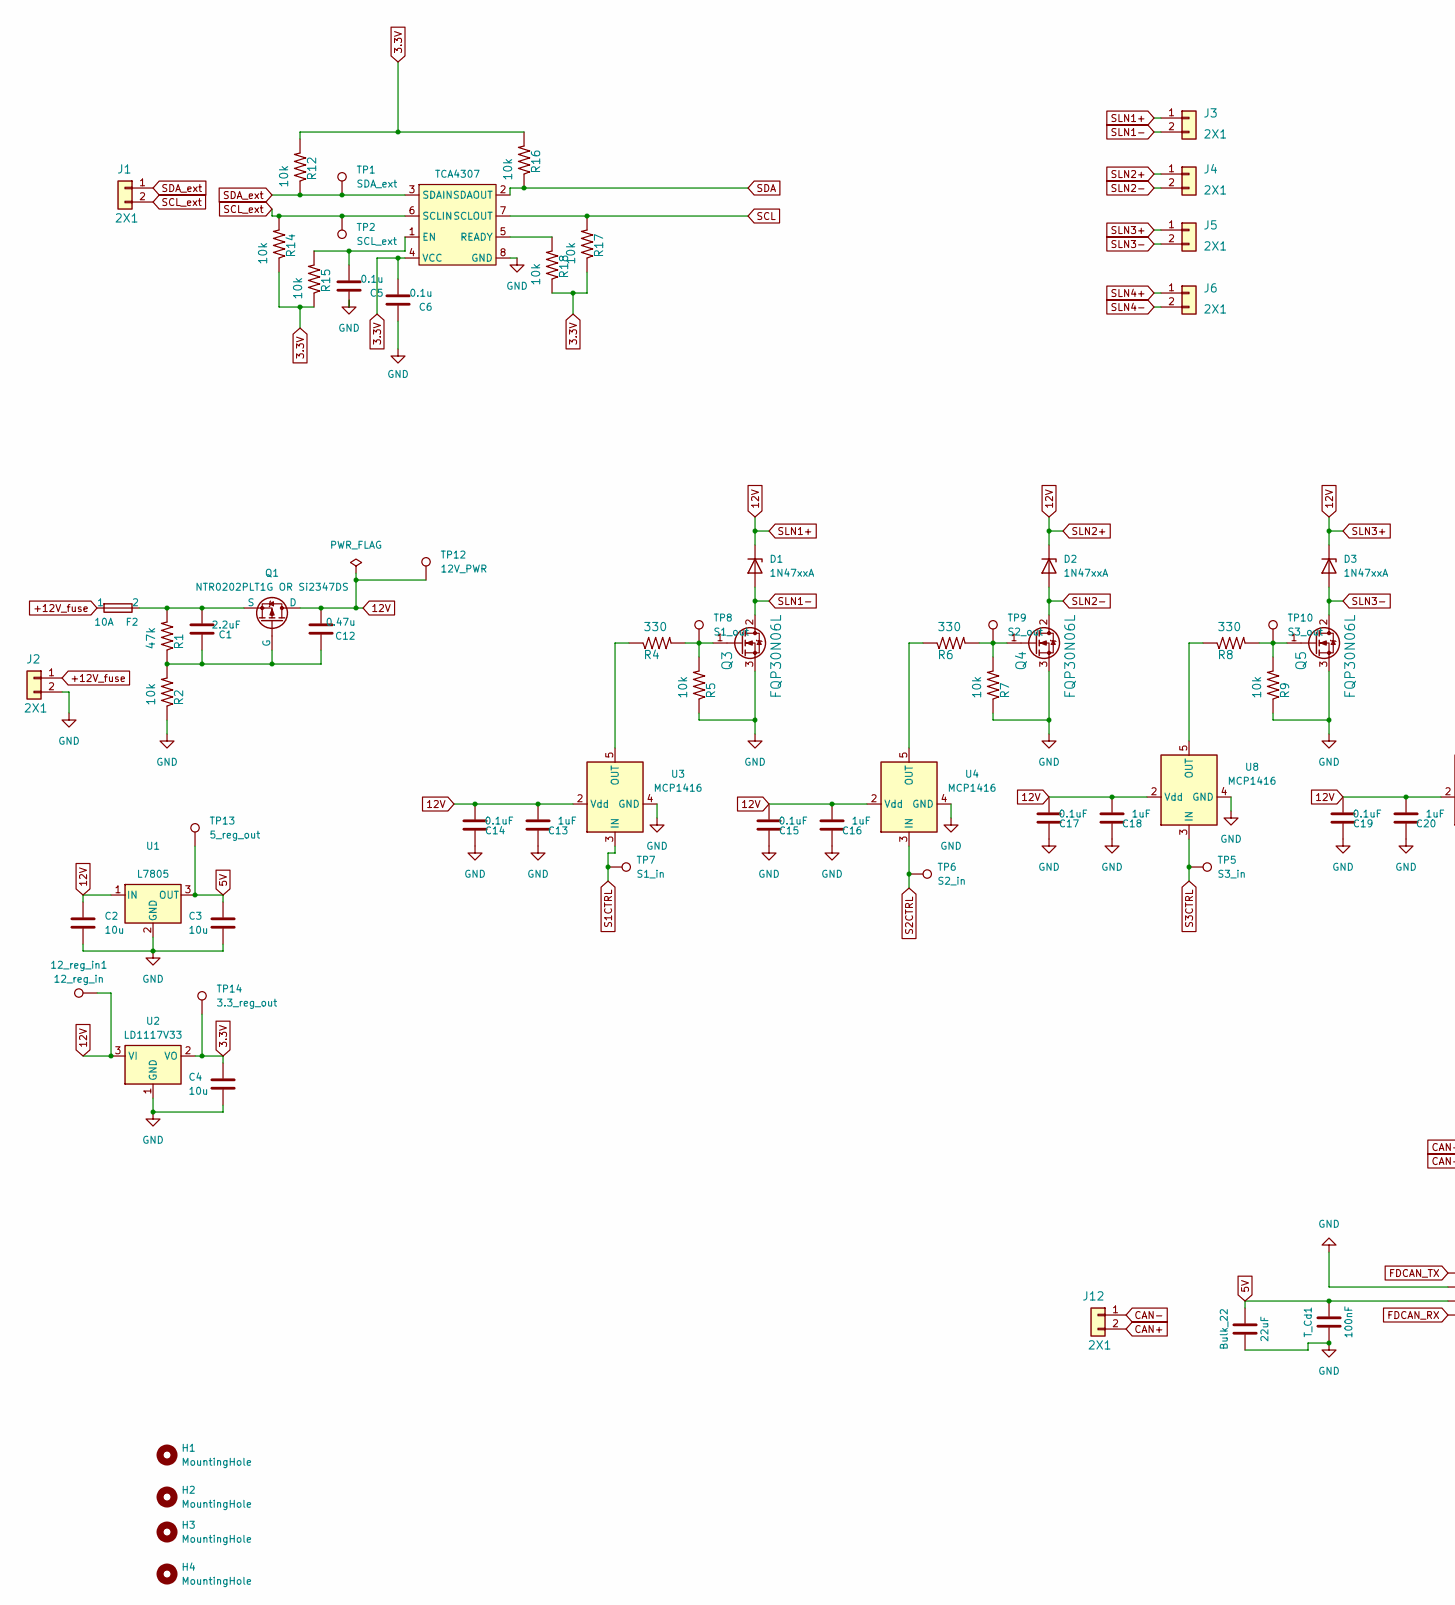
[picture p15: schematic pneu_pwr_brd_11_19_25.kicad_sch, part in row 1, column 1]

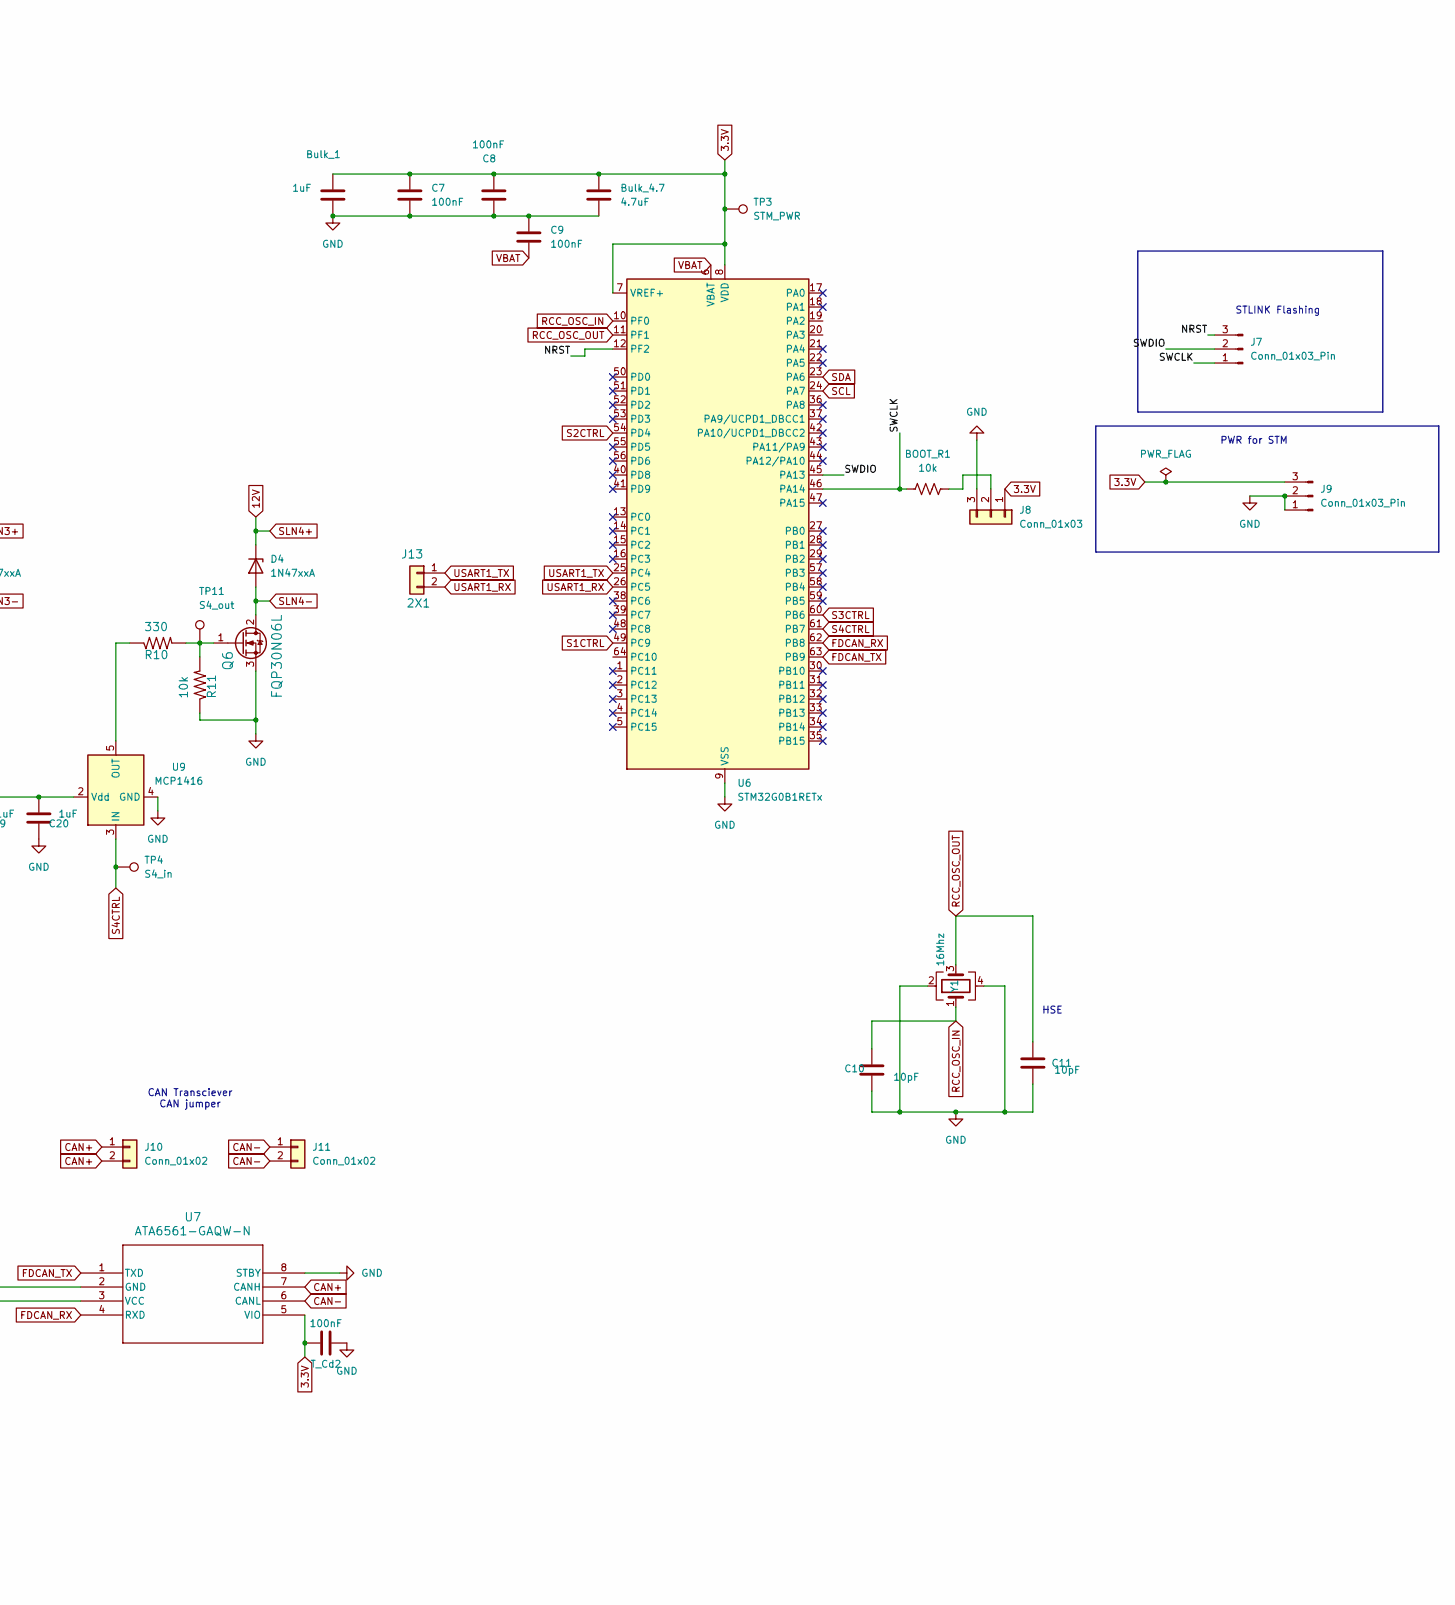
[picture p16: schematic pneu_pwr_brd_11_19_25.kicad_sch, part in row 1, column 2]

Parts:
12_reg_in1: 12_reg_in; TestPoint_Pad_D1.0mm
BOOT_R1: 10k; R_0805_2012Metric_Pad1.20x1.40mm_HandSolder
Bulk_1: 1uF; C_0805_2012Metric_Pad1.18x1.45mm_HandSolder
Bulk_4.7: 4.7uF; C_0805_2012Metric_Pad1.18x1.45mm_HandSolder
Bulk_22: 22uF; C_0805_2012Metric_Pad1.18x1.45mm_HandSolder
C1: 2.2uF; C_0402_1005Metric
C2, C3, C4: 10u; CP_Radial_D5.0mm_P2.00mm
C5, C6: 0.1u; C_0603_1608Metric
C7, C8, C9: 100nF; C_0805_2012Metric_Pad1.18x1.45mm_HandSolder
C10, C11: 10pF; C_0402_1005Metric_Pad0.74x0.62mm_HandSolder
C12: 0.47u; C_0402_1005Metric
C13, C16, C18, C20: 1uF; C_0402_1005Metric
C14, C15, C17, C19: 0.1uF; C_0402_1005Metric
D1, D2, D3, D4: 1N47xxA; D_DO-41_SOD81_P10.16mm_Horizontal
F2: 10A; Fuse_1206_3216Metric
H1, H2, H3, H4: MountingHole; MountingHole_3.2mm_M3_DIN965
J1, J2, J3, J4, J5, J6, J12, J13: 2X1; JST_PH_B2B-PH-K_1x02_P2.00mm_Vertical
J7, J9: Conn_01x03_Pin; PinHeader_1x03_P2.54mm_Vertical
J8: Conn_01x03; slide_switch_EGER1218_Thruster
J10, J11: Conn_01x02; PinHeader_1x02_P2.54mm_Vertical
Q1: NTR0202PLT1G OR Si2347DS; SOT-23-3
Q3, Q4, Q5, Q6: FQP30N06L; TO-220-3_Vertical
R1: 47k; R_0402_1005Metric
R2: 10k; R_0402_1005Metric
R4, R6, R8, R10: 330; R_0805_2012Metric_Pad1.20x1.40mm_HandSolder
R5, R7, R9, R11: 10k; R_0805_2012Metric_Pad1.20x1.40mm_HandSolder
R12, R14, R15, R16, R17, R18: 10k; R_0603_1608Metric
TP1: SDA_ext; TestPoint_Pad_D1.0mm
TP2: SCL_ext; TestPoint_Pad_D1.0mm
TP3: STM_PWR; TestPoint_Pad_D1.0mm
TP4: S4_in; TestPoint_Pad_D1.0mm
TP5: S3_in; TestPoint_Pad_D1.0mm
TP6: S2_in; TestPoint_Pad_D1.0mm
TP7: S1_in; TestPoint_Pad_D1.0mm
TP8: S1_out; TestPoint_Pad_D1.0mm
TP9: S2_out; TestPoint_Pad_D1.0mm
TP10: S3_out; TestPoint_Pad_D1.0mm
TP11: S4_out; TestPoint_Pad_D1.0mm
TP12: 12V_PWR; TestPoint_Pad_D1.0mm
TP13: 5_reg_out; TestPoint_Pad_D1.0mm
TP14: 3.3_reg_out; TestPoint_Pad_D1.0mm
T_Cd1, T_Cd2: 100nF; C_0805_2012Metric_Pad1.18x1.45mm_HandSolder
U1: L7805; TO-220-3_Vertical
U2: LD1117V33; TO-220-3_Vertical
U3, U4, U8, U9: MCP1416; SOT-23-5
U5: TCA4307; SOIC8_DGK_TEX
U6: STM32G0B1RETx; LQFP-64_10x10mm_P0.5mm
U7: ATA6561-GAQW-N; SOIC8_4P9X3P9MC_MCH
Y1: 16Mhz; Crystal_SMD_3225-4Pin_3.2x2.5mm

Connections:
3.3V: Bulk_1.2, Bulk_4.7.1, C4.1, C6.2, C7.1, C8.1, J8.1, J9.3, R12.2, R14.1, R15.1, R16.2, R17.1, R18.1, TP3.1, TP14.1, T_Cd2.1, U2.2 (VO), U5.4 (VCC), U6.7 (VREF+), U6.8 (VDD), U7.5 (VIO)
5V: Bulk_22.1, C3.1, TP13.1, T_Cd1.1, U1.3 (OUT), U7.3 (VCC)
12V: 12_reg_in1.1, C2.1, C12.2, C13.2, C14.2, C15.2, C16.2, C17.2, C18.2, C19.2, C20.2, D1.1 (K), D2.1 (K), D3.1 (K), D4.1 (K), J3.1, J4.1, J5.1, J6.1, Q1.1 (D), TP12.1, U1.1 (IN), U2.3 (VI), U3.2 (Vdd), U4.2 (Vdd), U8.2 (Vdd), U9.2 (Vdd)
+12V_fuse: F2.1, J2.1
/NRST: J7.3, U6.12 (PF2)
/SWCLK: BOOT_R1.1, J7.1, U6.46 (PA14)
/SWDIO: J7.2, U6.45 (PA13)
CAN+: J10.1, J10.2, J12.2, U7.7 (CANH)
CAN-: J11.1, J11.2, J12.1, U7.6 (CANL)
FDCAN_RX: U6.62 (PB8), U7.4 (RXD)
FDCAN_TX: U6.63 (PB9), U7.1 (TXD)
GND: Bulk_1.1, Bulk_4.7.2, Bulk_22.2, C2.2, C3.2, C4.2, C5.1, C6.1, C7.2, C8.2, C9.1, C10.2, C11.2, C13.1, C14.1, C15.1, C16.1, C17.1, C18.1, C19.1, C20.1, J2.2, J8.3, J9.1, J9.2, Q3.3 (S), Q4.3 (S), Q5.3 (S), Q6.3 (S), R2.1, R5.1, R7.1, R9.1, R11.1, T_Cd1.2, T_Cd2.2, U1.2 (GND), U2.1 (GND), U3.4 (GND), U4.4 (GND), U5.8 (GND), U6.9 (VSS), U7.2 (GND), U7.8 (STBY), U8.4 (GND), U9.4 (GND), Y1.2, Y1.4
unnamed: BOOT_R1.2, J8.2
unnamed: C1.1, C12.1, Q1.2 (G), R1.1, R2.2
unnamed: C1.2, F2.2, Q1.3 (S), R1.2
unnamed: Q3.1 (G), R4.2, R5.2, TP8.1
unnamed: Q4.1 (G), R6.2, R7.2, TP9.1
unnamed: Q5.1 (G), R8.2, R9.2, TP10.1
unnamed: Q6.1 (G), R10.2, R11.2, TP11.1
unnamed: R4.1, U3.5 (OUT)
unnamed: R6.1, U4.5 (OUT)
unnamed: C5.2, R15.2, U5.1 (EN)
unnamed: R18.2, U5.5 (READY)
unnamed: R8.1, U8.5 (OUT)
unnamed: R10.1, U9.5 (OUT)
RCC_OSC_IN: C10.1, U6.10 (PF0), Y1.1
RCC_OSC_OUT: C11.1, U6.11 (PF1), Y1.3
S1CTRL: TP7.1, U3.3 (IN), U6.49 (PC9)
S2CTRL: TP6.1, U4.3 (IN), U6.54 (PD4)
S3CTRL: TP5.1, U6.60 (PB6), U8.3 (IN)
S4CTRL: TP4.1, U6.61 (PB7), U9.3 (IN)
SCL: R17.2, U5.7 (SCLOUT), U6.24 (PA7)
SCL_ext: J1.2, R14.2, TP2.1, U5.6 (SCLIN)
SDA: R16.1, U5.2 (SDAOUT), U6.23 (PA6)
SDA_ext: J1.1, R12.1, TP1.1, U5.3 (SDAIN)
SLN1-: D1.2 (A), J3.2, Q3.2 (D)
SLN2-: D2.2 (A), J4.2, Q4.2 (D)
SLN3-: D3.2 (A), J5.2, Q5.2 (D)
SLN4-: D4.2 (A), J6.2, Q6.2 (D)
USART1_RX: J13.2, U6.26 (PC5)
USART1_TX: J13.1, U6.25 (PC4)
VBAT: C9.2, U6.6 (VBAT)

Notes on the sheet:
HSE
STLINK Flashing
CAN Transciever CAN jumper
PWR for STM

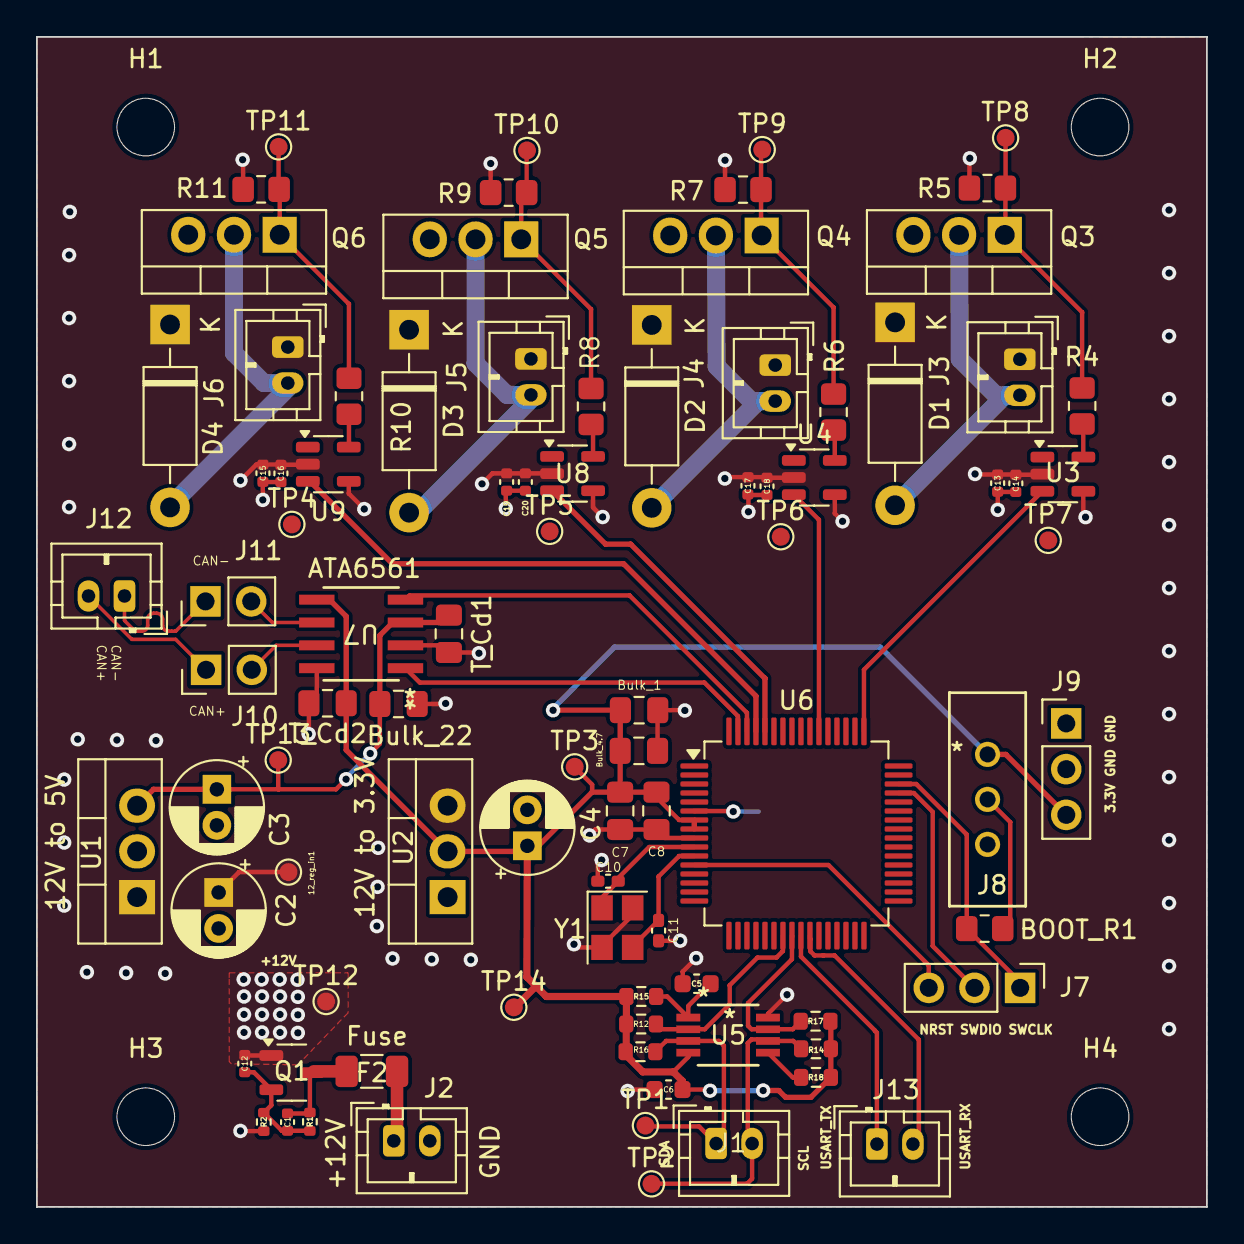
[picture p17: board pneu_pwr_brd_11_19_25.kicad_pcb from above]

Board: 4 copper layers, 65.0 x 65.0 mm, 94 parts (1 on the bottom side), 42 nets.

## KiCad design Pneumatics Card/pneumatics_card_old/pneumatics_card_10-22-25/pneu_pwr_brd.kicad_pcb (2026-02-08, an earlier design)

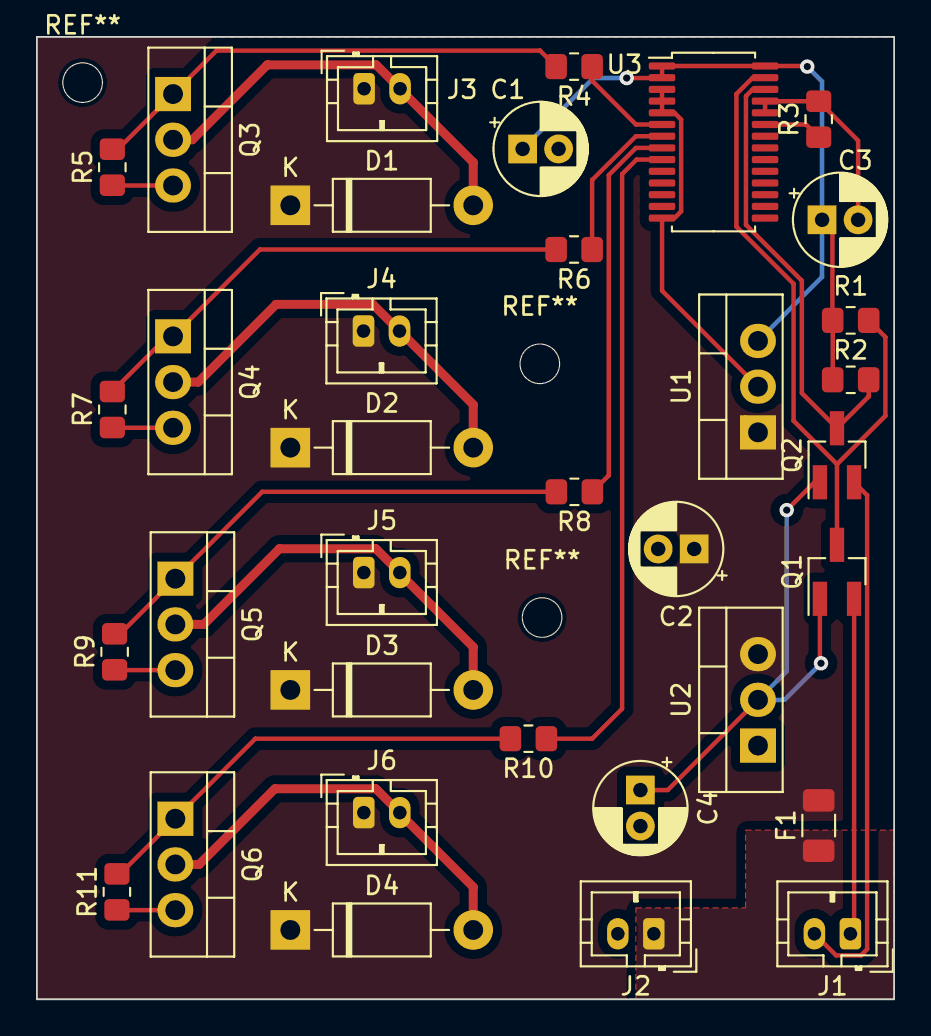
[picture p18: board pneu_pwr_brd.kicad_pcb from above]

Board: 2 copper layers, 47.6 x 53.5 mm, 35 parts (0 on the bottom side), 22 nets.

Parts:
C1, C2, C3, C4: 10u; CP_Radial_D5.0mm_P2.00mm
D1, D2, D3, D4: 1N47xxA; D_DO-41_SOD81_P10.16mm_Horizontal
F1: 10A; Fuse_1206_3216Metric
J1, J2, J3, J4, J5, J6: 2X1; JST_PH_B2B-PH-K_1x02_P2.00mm_Vertical
Q1, Q2: BSS138; SOT-23_Handsoldering
Q3, Q4, Q5, Q6: FQP30N06L; TO-220-3_Vertical
R1, R2: 4.7k; R_0805_2012Metric_Pad1.20x1.40mm_HandSolder
R3, R5, R7, R9, R11: 10k; R_0805_2012Metric_Pad1.20x1.40mm_HandSolder
R4, R6, R8, R10: 330; R_0805_2012Metric_Pad1.20x1.40mm_HandSolder
U1: L7805; TO-220-3_Vertical
U2: LD1117V33; TO-220-3_Vertical
U3: PCA9685; TSSOP-28_4.4x9.7mm_P0.65mm

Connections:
+3.3V: C4.1, Q1.1 (G), Q2.1 (G), U2.2 (VO)
+5V: C1.1, C3.1, R1.2, R2.1, U1.3 (OUT), U3.1 (A0), U3.2 (A1), U3.28 (VDD)
GND: C1.2, C2.2, C3.2, C4.2, J2.2, Q3.3 (S), Q4.3 (S), Q5.3 (S), Q6.3 (S), R3.2, R5.1, R7.1, R9.1, R11.1, U1.2 (GND), U2.1 (GND), U3.3 (A2), U3.4 (A3), U3.5 (A4), U3.14 (GND), U3.24 (A5), U3.25 (EXTCLK)
unnamed: J1.1, Q1.2 (D)
unnamed: J1.2, Q2.2 (D)
unnamed: F1.1, J2.1
unnamed: Q3.1 (G), R4.2, R5.2
unnamed: Q4.1 (G), R6.2, R7.2
unnamed: Q5.1 (G), R8.2, R9.2
unnamed: Q6.1 (G), R10.2, R11.2
unnamed: R3.1, U3.23 (OE')
S1CTRL: R4.1, U3.6 (PWM0)
S2CTRL: R6.1, U3.7 (PWM1)
S3CTRL: R8.1, U3.8 (PWM2)
S4CTRL: R10.1, U3.9 (PWM3)
SCL: Q2.3 (S), R2.2, U3.26 (SCL)
SDA: Q1.3 (S), R1.1, U3.27 (SDA)
SLN1+: C2.1, D1.1 (K), D2.1 (K), D3.1 (K), D4.1 (K), F1.2, J3.1, J4.1, J5.1, J6.1, U1.1 (IN), U2.3 (VI)
SLN1-: D1.2 (A), J3.2, Q3.2 (D)
SLN2-: D2.2 (A), J4.2, Q4.2 (D)
SLN3-: D3.2 (A), J5.2, Q5.2 (D)
SLN4-: D4.2 (A), J6.2, Q6.2 (D)

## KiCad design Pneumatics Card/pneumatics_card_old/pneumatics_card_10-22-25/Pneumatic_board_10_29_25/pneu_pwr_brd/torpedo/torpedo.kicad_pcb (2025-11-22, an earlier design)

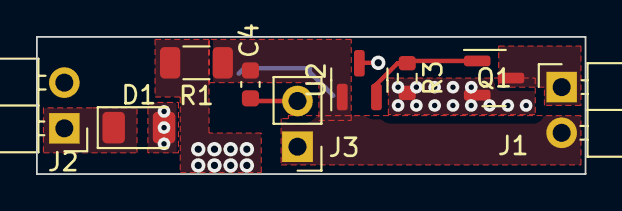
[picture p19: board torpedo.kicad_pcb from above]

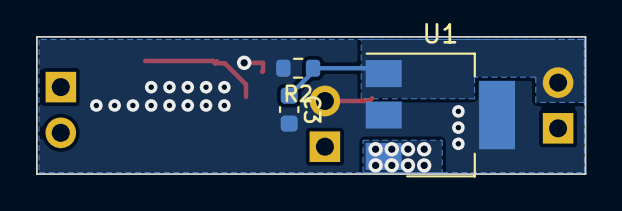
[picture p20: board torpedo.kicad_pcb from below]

Board: 2 copper layers, 30.5 x 7.6 mm, 12 parts (3 on the bottom side), 7 nets.

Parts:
C3: 1u; C_0603_1608Metric
C4: 10n; C_0603_1608Metric
D1: SD1206S100S1R0; D_1206_3216Metric
J1: Motor; PinHeader_1x02_P2.54mm_Horizontal
J2: Battery; PinHeader_1x02_P2.54mm_Horizontal
J3: Capacitors; PinHeader_1x02_P2.54mm_Vertical
Q1: DMG2301L; SOT-23
R1: 10; R_1206_3216Metric
R2, R3: 10k; R_0603_1608Metric
U1: LM340-5.0; SOT-223-3_TabPin2
U2: AH372X; SOT-23

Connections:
+6V: C4.1, J1.2, J3.1, R1.1, U2.1 (VDD)
GND: C3.2, C4.2, D1.2 (A), J3.2, Q1.2 (S), R2.2, R3.2, U1.2 (GND), U2.3 (GND)
unnamed: D1.1 (K), J2.1
unnamed: J1.1, Q1.3 (D)
unnamed: C3.1, J2.2, R2.1, U1.1 (VI)
unnamed: R1.2, U1.3 (VO)
SW: Q1.1 (G), R3.1, U2.2 (Output)

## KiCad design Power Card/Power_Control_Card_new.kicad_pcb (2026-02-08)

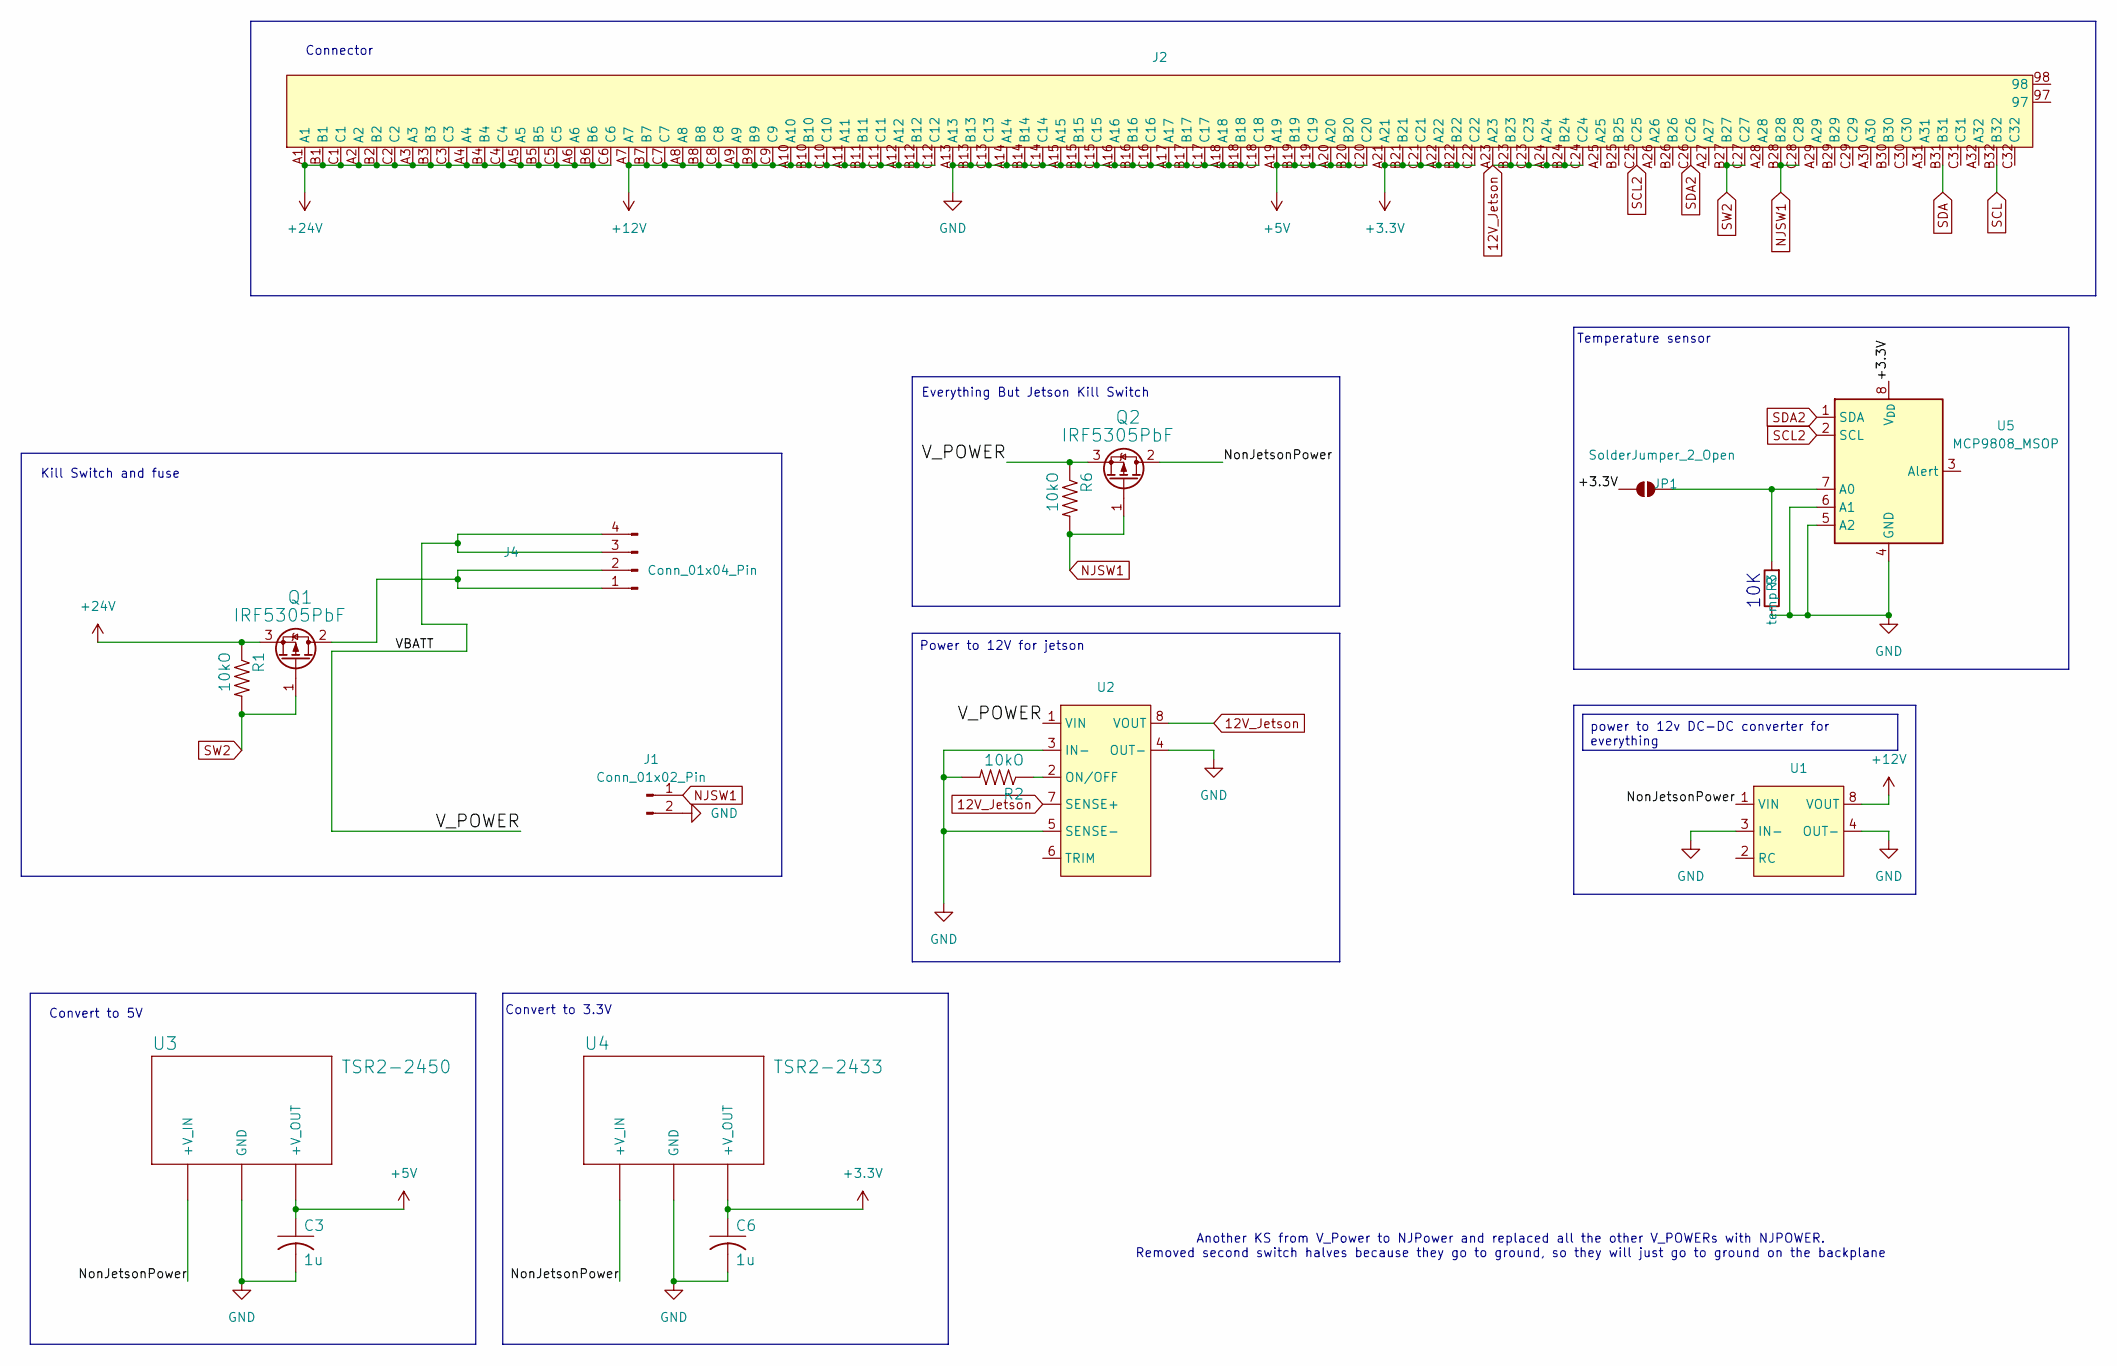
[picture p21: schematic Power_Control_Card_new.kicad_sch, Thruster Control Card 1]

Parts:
C3, C6: 1u; C_0805_2012Metric_Pad1.18x1.45mm_HandSolder
J1: Conn_01x02_Pin; PinSocket_1x02_P2.54mm_Vertical
J2: 6509475
J4: Conn_01x04_Pin; 1.25__FUSECLIPS
JP1: SolderJumper_2_Open; SolderJumper-2_P1.3mm_Open_RoundedPad1.0x1.5mm
Q1, Q2: IRF5305PbF; TO-220-3_Vertical
R1, R2, R6: 10kO; R_0805_2012Metric_Pad1.20x1.40mm_HandSolder
R3: temp R; R_0805_2012Metric_Pad1.20x1.40mm_HandSolder
U1: 240W_CONV
U2: 72W_CONV
U3: TSR2-2450; TSR2 DC/DC Converter
U4: TSR2-2433; TSR2 DC/DC Converter
U5: MCP9808_MSOP; MSOP-8_3x3mm_P0.65mm

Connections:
12V_Jetson: J2.A23, J2.A24, J2.B23, J2.B24, J2.C23, J2.C24, U2.7 (SENSE+), U2.8 (VOUT)
+3.3V: C6.1, J2.A21, J2.A22, J2.B21, J2.B22, J2.C21, J2.C22, JP1.1 (A), U4.3 (+V_OUT), U5.8 (V_{DD})
+5V: C3.1, J2.A19, J2.A20, J2.B19, J2.B20, J2.C19, J2.C20, U3.3 (+V_OUT)
+12V: J2.A7, J2.A8, J2.A9, J2.A10, J2.A11, J2.A12, J2.B7, J2.B8, J2.B9, J2.B10, J2.B11, J2.B12, J2.C7, J2.C8, J2.C9, J2.C10, J2.C11, J2.C12, U1.8 (VOUT)
+24V: J2.A1, J2.A2, J2.A3, J2.A4, J2.A5, J2.A6, J2.B1, J2.B2, J2.B3, J2.B4, J2.B5, J2.B6, J2.C1, J2.C2, J2.C3, J2.C4, J2.C5, J2.C6, Q1.3 (S), R1.1
/NonJetsonPower: Q2.2 (D), U1.1 (VIN), U3.1 (+V_IN), U4.1 (+V_IN)
/VBATT: J4.3, J4.4, Q2.3 (S), R6.1, U2.1 (VIN)
GND: C3.2, C6.2, J1.2, J2.A13, J2.A14, J2.A15, J2.A16, J2.A17, J2.A18, J2.B13, J2.B14, J2.B15, J2.B16, J2.B17, J2.B18, J2.C13, J2.C14, J2.C15, J2.C16, J2.C17, J2.C18, R2.2, R3.1, U1.3 (IN-), U1.4 (OUT-), U2.3 (IN-), U2.4 (OUT-), U2.5 (SENSE-), U3.2 (GND), U4.2 (GND), U5.4 (GND), U5.5 (A2), U5.6 (A1)
NJSW1: J1.1, J2.B28, J2.C28, Q2.1 (G), R6.2
unnamed: J4.1, J4.2, Q1.2 (D)
unnamed: JP1.2 (B), R3.2, U5.7 (A0)
unnamed: R2.1, U2.2 (ON/OFF)
SCL: J2.B32
SCL2: J2.C25, U5.2 (SCL)
SDA: J2.B31
SDA2: J2.C26, U5.1 (SDA)
SW2: J2.B27, J2.C27, Q1.1 (G), R1.2

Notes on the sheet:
Convert to 3.3V
Kill Switch and fuse
Connector
Temperature sensor
Another KS from V_Power to NJPower and replaced all the other V_POWERs with NJPOWER. Removed second switch halves because they go to ground, so they will just go to ground on the backplane
Convert to 5V
Everything But Jetson Kill Switch
10K
power to 12v DC-DC converter for everything
Power to 12V for jetson



Board: 2 copper layers, 100.0 x 62.5 mm, 17 parts (2 on the bottom side), 15 nets.

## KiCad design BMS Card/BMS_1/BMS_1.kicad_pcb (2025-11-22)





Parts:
BOOT_R1: 10k; R_0805_2012Metric_Pad1.20x1.40mm_HandSolder
Bulk_1: 1uF; C_0805_2012Metric_Pad1.18x1.45mm_HandSolder
Bulk_4.7: 4.7uF; C_0805_2012Metric_Pad1.18x1.45mm_HandSolder
Bulk_22: 22uF; C_0603_1608Metric
C5, C6, C7: 100nF; C_0805_2012Metric_Pad1.18x1.45mm_HandSolder
C14, C16, C28, C29, C35, C36, C37, C38: 0.22uF; C_0603_1608Metric
C15: 0.47uF; C_0603_1608Metric
C17: 2.2uF; C_1206_3216Metric
C18, C21: 100pF; C_0603_1608Metric
C20, C23, C24, C25, C26: 0.1uF; C_0603_1608Metric
C22: 2.2uF; C_0603_1608Metric_Pad1.08x0.95mm_HandSolder
C32: 2.2uF; C_0402_1005Metric
C33: 22uF; C_0402_1005Metric
C42: 0.1uF; C_0402_1005Metric_Pad0.74x0.62mm_HandSolder
C43: 1uF; C_0603_1608Metric
D1, D6, D10, D11, D12, D13: BAV16W; D_SOD-523
D2: BAV16W; D_SOD-123
D3, D5: 16V MMSZ5246B-7-F; D_SOD-123
D4: 100V; D_SOD-123
J1, J9: Conn_01x03_Pin; PinHeader_1x03_P2.54mm_Vertical
J3: Conn_01x02; AMASS_XT30UPB-M_1x02_P5.0mm_Vertical
J4: Conn_01x02; AMASS_XT30UPB-F_1x02_P5.0mm_Vertical
J5: Conn_01x07; JST_XH_S7B-XH-A-1_1x07_P2.50mm_Horizontal
J6: Conn_01x02; JST_PH_B2B-PH-K_1x02_P2.00mm_Vertical
J8: Conn_01x03; slide_switch_EGER1218_Thruster
L2: 10uH; L_Coilcraft_XxL4040
NT1: NetTie_2; NetTie-2_THT_Pad1.0mm
Q2, Q3: CSD17327Q5A; TDSON-8-1
Q4, Q5, Q9, Q10, Q11, Q12: NMOS; SOT-23_Handsoldering
R8, R9: 0.004; R_2512_6332Metric
R11, R12, R13, R29, R33, R35, R37, R61, R62, R64, R66, R71, R72, R74, R76: 100; R_0603_1608Metric_Pad0.98x0.95mm_HandSolder
R14, R15: 4.7k; R_0603_1608Metric_Pad0.98x0.95mm_HandSolder
R16: 5.1k; R_0805_2012Metric_Pad1.20x1.40mm_HandSolder
R17, R21: 10M; R_0603_1608Metric_Pad0.98x0.95mm_HandSolder
R18, R19, R20, R22, R23, R24, R25: 5.1k; R_0603_1608Metric_Pad0.98x0.95mm_HandSolder
R26, R27: 1K; R_0603_1608Metric_Pad0.98x0.95mm_HandSolder
R30, R34, R36, R63, R65, R73, R75: 10K; R_0603_1608Metric_Pad0.98x0.95mm_HandSolder
R31: 3.5K; R_0603_1608Metric_Pad0.98x0.95mm_HandSolder
R32: 2M; R_0603_1608Metric_Pad0.98x0.95mm_HandSolder
R47, R49, R57, R58, R67, R68: 25; R_1206_3216Metric
TH1, TH2: Thermistor_NTC_US; THRMC1608X95N
T_Cd1: 100nF; C_0603_1608Metric
T_Cd2: 100nF; C_0603_1608Metric_Pad1.08x0.95mm_HandSolder
U1: PBQ76942PFBT; PFB0048A_L
U2: TLV70430DBVR; DBV0005A_L
U5: STM32G0B1RETx; LQFP-64_10x10mm_P0.5mm
U6: ATA6561-GAQW-N; SOIC8_4P9X3P9MC_MCH
U7: TPS62175DQCR; WSON-10-1EP_2x3mm_P0.5mm_EP0.84x2.4mm_ThermalVias

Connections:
3.3v: Bulk_1.2, Bulk_4.7.1, C5.1, C7.1, C43.2, J8.1, J9.3, T_Cd2.1, U2.3 (OUT), U5.7 (VREF+), U5.8 (VDD), U6.5 (VIO)
5V: Bulk_22.1, C33.1, C42.1, L2.2, R14.2, R15.2, R30.1, R32.1, T_Cd1.1, U2.2 (IN), U6.3 (VCC), U7.8 (SLEEP), U7.10 (VOS)
/NRST: J1.1, U5.12 (PF2)
/SWCLK: BOOT_R1.1, J1.3, U5.46 (PA14)
/SWDIO: J1.2, U5.45 (PA13)
BAT+: C23.2, C32.1, D2.2 (A), D3.2 (A), J4.1, Q3.1 (S), Q3.2 (S), Q3.3 (S), R17.1, U7.2 (VIN), U7.3 (EN)
BAT-: J4.2, NT1.2, R8.2, R9.2, R13.2
CAN+: J6.1, U6.7 (CANH)
CAN-: J6.2, U6.6 (CANL)
CHG: R16.2, U1.45 (CHG)
Cell 1: D12.2 (A), J5.6, Q11.3 (S), R68.2, R72.2, R74.2
Cell 2: D11.2 (A), J5.5, Q10.3 (S), R66.2, R67.2, R71.2
Cell 3: D10.2 (A), J5.4, Q9.3 (S), R58.2, R62.2, R64.2
Cell 4: D6.2 (A), J5.3, Q5.3 (S), R37.2, R57.2, R61.2
Cell 5: D1.2 (A), J5.2, Q4.3 (S), R33.2, R35.2, R49.2
Cell 6: J5.1, R29.2, R47.2
Cell (Stack Bottom): D13.2 (A), J5.7, Q12.3 (S), R76.2
DSG: D4.1 (K), R19.2, U1.43 (DSG)
FDCAN_RX: U5.59 (PB5), U6.4 (RXD)
FDCAN_TX: U5.60 (PB6), U6.1 (TXD)
GND: Bulk_1.1, Bulk_4.7.2, Bulk_22.2, C5.2, C6.1, C7.2, C14.1, C16.2, C17.2, C18.1, C22.2, C32.2, C33.2, C42.2, C43.1, J8.3, J9.1, J9.2, NT1.1, R26.2, R27.2, R31.1, TH1.1, TH2.2, T_Cd1.2, T_Cd2.2, U1.17 (VSS), U1.36 (REGIN), U1.37 (BREG), U2.1 (GND), U5.9 (VSS), U6.2 (GND), U6.8 (STBY), U7.1 (PGND), U7.4 (NC), U7.6 (AGND), U7.11 (PAD)
LD: R25.1, U1.41 (LD)
unnamed: C23.1, C24.2
unnamed: C25.1, C26.2
unnamed: D1.1 (K), Q4.2 (G), R34.2
unnamed: D2.1 (K), R11.2
unnamed: D3.1 (K), Q3.4 (G), R16.1, R17.2
unnamed: D4.2 (A), R20.2
unnamed: D5.1 (K), Q2.4 (G), R18.1, R20.1, R21.2
unnamed: D6.1 (K), Q5.2 (G), R36.2
unnamed: D10.1 (K), Q9.2 (G), R63.2
unnamed: D11.1 (K), Q10.2 (G), R65.2
unnamed: D12.1 (K), Q11.2 (G), R73.2
unnamed: D13.1 (K), Q12.2 (G), R75.2
unnamed: BOOT_R1.2, J8.2
unnamed: Q4.1 (D), R47.1
unnamed: Q5.1 (D), R49.1
unnamed: Q9.1 (D), R57.1
unnamed: Q10.1 (D), R58.1
unnamed: Q11.1 (D), R67.1
unnamed: Q12.1 (D), R68.1
unnamed: R18.2, R19.1
unnamed: R22.1, R24.2
unnamed: R23.1, R25.2
unnamed: C15.1, C17.1, C18.2, R11.1, U1.47 (BAT)
unnamed: C15.2, U1.46 (CP1)
unnamed: R27.1, U1.28 (HDQ)
unnamed: C22.1, U1.24 (REG18)
unnamed: R26.1, U1.33 (RST_SHUT)
unnamed: TH1.2, U1.21 (TS1)
unnamed: TH2.1, U1.23 (TS3)
unnamed: C16.1, C38.2, R75.1, R76.1, U1.16 (VC0)
unnamed: C14.2, C37.2, C38.1, R72.1, R73.1, R74.1, U1.15 (VC1)
unnamed: C36.2, C37.1, R65.1, R66.1, R71.1, U1.14 (VC2)
unnamed: C35.2, C36.1, R62.1, R63.1, R64.1, U1.13 (VC3)
unnamed: C29.2, C35.1, R36.1, R37.1, R61.1, U1.12 (VC4)
unnamed: C28.2, C29.1, R33.1, R34.1, R35.1, U1.2 (VC9), U1.4 (VC8), U1.6 (VC7), U1.8 (VC6), U1.10 (VC5)
unnamed: C28.1, R29.1, U1.48 (VC10)
unnamed: R31.2, R32.2, U7.5 (FB)
unnamed: R30.2, U7.7 (PG)
unnamed: L2.1, U7.9 (SW)
PACK: R24.1, U1.42 (PACK)
PACK+: C24.1, C25.2, D5.2 (A), J3.1, Q2.1 (S), Q2.2 (S), Q2.3 (S), R21.1, R22.2, R23.2
PACK-: C26.1, J3.2, R8.1, R9.1, R12.2
Q_D: Q2.5 (D), Q3.5 (D)
SCL: R15.1, U1.26 (SCL), U5.24 (PA7)
SDA: R14.1, U1.27 (SDA), U5.23 (PA6)
SRN: C20.2, C21.1, R12.1, U1.20 (SRN)
SRP: C20.1, C21.2, R13.1, U1.18 (SRP)
VBAT: C6.2, U5.6 (VBAT)

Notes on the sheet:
CAN Transciever
PWR for STM
STM32 MCU
STLINK Flashing
5V Buck Converter
Current Sense
Balance Connector
5V to 3.3V Linear Regulator
Load Connector
Balancing and Voltage Sensing
5V Regulator
Charge and Discharge Protection
Battery Connector


Board: 2 copper layers, 105.1 x 55.3 mm, 111 parts (1 on the bottom side), 70 nets.

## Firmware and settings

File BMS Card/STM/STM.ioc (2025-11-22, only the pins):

Mcu.UserName=STM32G0B1RETxN
PA6.Signal=I2C2_SDA
PA7.Signal=I2C2_SCL
PB5.Signal=FDCAN2_RX
PB6.Signal=FDCAN2_TX

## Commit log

2025-11-22 Added Power Card
    [650947-5.stp, Power_Control_Card.kicad_pcb, Power_Control_Card.kicad_sch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]
2025-11-22 Added empty folders for other cards and a readme
    [650947-5.stp, Power_Control_Card.kicad_pcb, Power_Control_Card.kicad_sch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]
2025-11-22 Added Backplane
    [Backplane.kicad_pcb, Backplane.kicad_sch]
2025-11-22 Added Thruster Card
    [Power_Control_Card.kicad_pcb, Power_Control_Card.kicad_sch, Thruster_Control_Card.kicad_pcb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]
2025-11-22 Added Pneumatics Card
    [SLW-1276864-4A-D.step, TCA4307DGKR.STEP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]
2025-11-22 removed folder nest
    [SLW-1276864-4A-D.step, TCA4307DGKR.STEP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]
2025-11-22 Removed Pneumatics Card Backups
    [SLW-1276864-4A-D.step, TCA4307DGKR.STEP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]
2025-11-22 Added Misc Card
    [Misc_Control_Card_v4.kicad_pcb, Misc_Control_Card_v4.kicad_sch]
2025-11-22 Added BMS
    [BMS_1.kicad_pcb, BMS_1.kicad_sch, DQC0010A.stp]
2025-11-22 testing some stuff
    [Power_Control_Card_new.kicad_sch]
2025-11-22 test msg
    [Power_Control_Card_new.kicad_sch]
2025-11-23 Changed Backplane and Power Card for proper connection between the killswitches in the new system
    [Backplane.kicad_pcb, Backplane.kicad_sch, Power_Control_Card_new.kicad_pcb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]
2025-11-24 Added the Mosfet drivers
    [pneu_pwr_brd_11_19_25.kicad_pcb, pneu_pwr_brd_11_19_25.kicad_sch]
2025-11-24 Redid the Layout with new components
    Increased board size to 63x63mm, added mounting holes (need to recheck), traces not routed yet.
    [pneu_pwr_brd_11_19_25.kicad_pcb, pneu_pwr_brd_11_19_25.kicad_sch]
2025-11-24 Moved the I2C protection for better tracing
    [pneu_pwr_brd_11_19_25.kicad_pcb]
2025-11-25 Fixed the footprints and silkscreens
    [TCA4307DGKR.STEP, pneu_pwr_brd_11_19_25.kicad_pcb, pneu_pwr_brd_11_19_25.kicad_sch]
2025-11-29 Made most of routing
    [pneu_pwr_brd_11_19_25.kicad_pcb, pneu_pwr_brd_11_19_25.kicad_sch]
2025-12-01 Finished Tracing
    Added USART, Mounting Hole, Stiching Vias, Proper 12V connection.
    [pneu_pwr_brd_11_19_25.kicad_pcb]
2025-12-01 Integrated Mounting Holes and made PCB 65x65
    [pneu_pwr_brd_11_19_25.kicad_pcb]
2025-12-01 Changed some Silk-screen and measured hole size
    [pneu_pwr_brd_11_19_25.kicad_pcb]
2025-12-03 Ramp rate values
    [pneu_pwr_brd_11_19_25.kicad_sch]
2025-12-07 Change the M3 hole
    [pneu_pwr_brd_11_19_25.kicad_pcb, pneu_pwr_brd_11_19_25.kicad_sch]
2025-12-07 Added more vias to 12V and GND plane
2026-01-14 added and fix temp sensor and error
    [Power_Control_Card_new.kicad_pcb, Power_Control_Card_new.kicad_sch]
2026-02-05 actually connected the njsw1 resistor
    [Power_Control_Card_new.kicad_pcb]
2026-02-08 Added old pneumatics card for back up
    [pneu_pwr_brd-B_Cu.gbr, pneu_pwr_brd-B_Mask.gbr, pneu_pwr_brd-B_Paste.gbr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]
2026-02-08 added inrush protection to old pneumatics board
    [pneu_pwr_brd.kicad_sch]
2026-02-08 Added short on power card and fixed some connections
    [Backplane.kicad_pcb]
2026-02-08 2nd Kill switch short and fixed connections
    [Power_Control_Card_new.kicad_pcb]
2026-02-08 fixed footprint for old pneumatics card
    [pneu_pwr_brd.kicad_sch]
2026-02-08 NJKS short
    [Power_Control_Card_new.kicad_sch]
2026-02-08 PCB for old pneumatics card
2026-02-08 annotating schematic
    [pneu_pwr_brd.kicad_sch]
2026-02-08 old pneumatics fixing PCB
    [pneu_pwr_brd.kicad_pcb]
2026-02-08 Corrected CANBUS routing Length.
    [pneu_pwr_brd_11_19_25.kicad_pcb]
2026-02-08 added inrush protection to pcb
    [pneu_pwr_brd.kicad_pcb]
2026-02-12 old pneumatics
    [pneu_pwr_brd-B_Cu.gbr, pneu_pwr_brd-B_Mask.gbr, pneu_pwr_brd-B_Paste.gbr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]
2026-02-12 old pneumatics added mounting holes
    [pneu_pwr_brd.kicad_pcb]
2026-02-12 Fixed the i2c line
    [Power_Control_Card_new.kicad_sch]
2026-02-12 routed pneumatics pcb
    [pneu_pwr_brd.kicad_pcb]
2026-02-12 finished back up pneumatics
    [pneu_pwr_brd-B_Cu.gbr, pneu_pwr_brd-B_Mask.gbr, pneu_pwr_brd-B_Paste.gbr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]
2026-02-15 Changed resistor values
    [pneu_pwr_brd_11_19_25.kicad_pcb, pneu_pwr_brd_11_19_25.kicad_sch]
2026-02-22 Put Back up pneumatics board in proper location
    [pneu_pwr_brd_11_19_25-B_Cu.gbr, pneu_pwr_brd_11_19_25-B_Mask.gbr, pneu_pwr_brd_11_19_25-B_Paste.gbr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]
2026-03-01 fixed the traces, added test point, fixed some silkscreen
    [pneu_pwr_brd_11_19_25.kicad_pcb, pneu_pwr_brd_11_19_25.kicad_sch]
2026-04-15 Uploaded misc board from 4/15/2026
    [Misc_Control_Card (1) (2).kicad_pcb, Misc_Control_Card (1) (2).kicad_sch]
2026-04-22 Added CAN Impedance Matching
    Misc Card
    [Misc_Control_Card (1) (2).kicad_pcb, Misc_Control_Card (1) (2).kicad_sch, Misc_Control_Card_v4.kicad_pcb]
2026-04-22 Added Silkscreen & Backplane Integration
    [Backplane.kicad_pcb, Backplane.kicad_sch, Misc_Control_Card (1) (2).kicad_pcb]
2026-04-23 Kurt Changes
    [Backplane.kicad_pcb]
2026-04-26 Added More Connectors to Backplane
    [Backplane.kicad_pcb, Backplane.kicad_sch]
2026-04-26 Moved I2C Pins for Power Card
    [Backplane.kicad_pcb, Backplane.kicad_sch]
2026-05-25 New STEP Models
    [Backplane-B_Cu.gbl, Backplane-B_Mask.gbs, Backplane-B_Paste.gbp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]
